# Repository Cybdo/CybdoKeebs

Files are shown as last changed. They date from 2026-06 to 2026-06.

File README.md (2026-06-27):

# CybdoKeebs!

A hotswappable ecosystem of i2c powered keyboard modules!

Zine

I made this project because I wanted to make something cooler than a macropad, and being able to just swap stuff around seemed really sick.

Inspired by [Ocreeb](https://www.youtube.com/watch?v=7DfexfHzT-w)!

# File structure

everything for each module is found under `modules/[module name]`, including CAD files, EDA files and firmware.

# Features
 - plug and play
 - hotswappable modules
 - exposed I2C buses
 - fully open source!
 - supports any MX-footprint keyswitches!
 - inbuilt USB hub in the controller

# Firmware
Firmware runs on circuitpython, and the firmware for each module is under `modules/[module name]/firmware`. Flash it using the SWD ports on each module, or via USB on the controller hub. You may need a SWD to USB converter, which can be made using a Raspberry Pi Pico.

# Custom modules
Each module is made as a composite of "sub units", each being 6cm tall and 5cm wide, with male pogo pins on the top and left sides, and female recievers on the bottom and right sides. These can be found here: https://www.aliexpress.com/item/1005005284441979.html

# Assembly
Everything is designed to be tray mounted, as to not obstruct the pogo pin assemblies! This means, the plate snaps into and are held up by keyswitches.

To put the keyboard together, put 4 keyswitches in each of the corners of the plate, then put the keyswitches through their sockets. After checking that everything is aligned, put in the rest of the switches!

assembled render

# BOM
found at `bom.csv`, assuming 1 controller hub, one keyboard and one macropad

# Schematics

## Hub


## Macropad



## Keyboard



# PCB

## Hub



## Macropad



## Keyboard




# Acknowledgements
 - [KiCad](https://www.kicad.org)
 - [Hack Club Fallout](https://fallout.hackclub.com)
 - [Ocreeb V2](https://github.com/sb-ocr/ocreeb-mk-2)
 - [CircuitPython](https://circuitpython.org/)
 - [ai03 Plate Generator](https://kbplate.ai03.com/)
 - [Hack Club Hackpad](https://hackpad.hackclub.com)

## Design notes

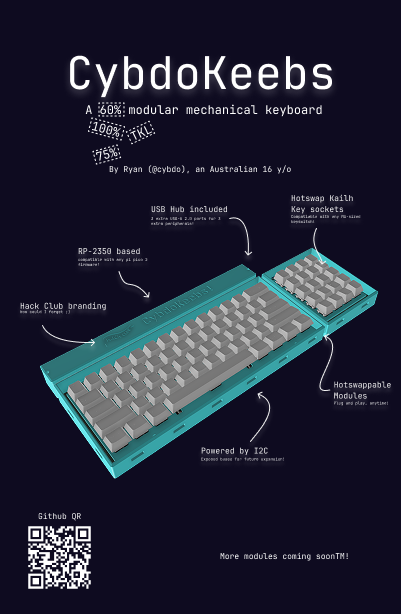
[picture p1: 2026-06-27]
assets/Zine.png

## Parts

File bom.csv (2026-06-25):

Item | Price ea (USD) | Qty | Price Total (USD) | Link | notes
bom-lcsc-minimum-system.xls (for 3 modules) | 17.82 | 1 | 13.87 | https://lcsc.com | for 3 modules accounting for MOQ, see bom-lcsc-minimum-system.xls and excl shipping
MX keyswitches 110 pcs | 19.62 | 1 | 19.62 | https://www.aliexpress.com/item/1005008998414457.html?curPageLogUid=2fVVZGWjHTVD
M3 screw 100pcs | 1.25 | 1 | 1.25 | https://www.aliexpress.com/item/32869840993.html
M3 heat set insert | 1 | 1 | 1 | https://www.aliexpress.com/item/1005004870993068.html
Kailh hot swap sockets 110 pcs | 5.61 | 1 | 5.61 | https://www.aliexpress.com/item/1005004290562374.html?scm_id=1007.10668.445195.0&scm-url=1007.10668.445195.0
PCB 5pcsof each | 49.59 | 1 | 49.59 | https://jlcpcb.com | including shipping
Stabiliser set | 1.53 | 1 | 1.53 | https://www.aliexpress.com/item/1005001543613992.html?curPageLogUid=S7IBJ0clB4Oz&utparam-url=scene%3Asearch|query_from%3A|x_object_id%3A1005001543613992|_p_origin_prod%3A
134 key keycap set | 3.17 | 1 | 3.17 | https://www.aliexpress.com/item/1005010601642425.html?curPageLogUid=OfD1pAizMWyY&utparam-url=scene%3Asearch|query_from%3A|x_object_id%3A1005010601642425|_p_origin_prod%3A&search_p4p_id=202606210629565832799410249750002134707_6
1N4148W | 0.0246 | 100 | 2.46 | https://www.lcsc.com/product-detail/C176288.html | for each keyswitch, not incl in lcsc bom
pogo pins 5pin 5pk | 6.46 | 4 | 25.84 | https://www.aliexpress.com/item/1005005284441979.html?curPageLogUid=fmbIcUrpBbfC
bom-lcsc-hub.xls (for the control hub) | 19.51 | 1 | 19.51 | https://lcsc.com | see bom-lcsc-hub.xls, excl shipping
TOTAL |  |  | 143.45

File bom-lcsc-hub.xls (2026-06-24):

bom_CybdoKeebs_hub.csv |  |  |  |  |  |  |  |  |  | LCSC BOM Quotation
 |  |  |  |  |  |  |  |  |  | BOM Date Created：24/06/26 18:42:51 |  |  |  | BOM Export Date: 24/06/26 18:52:30 |  |  |  | The matching result is a real-time query result, availability and prices may fluctuate. Backorder items are estimated prices for your reference, please submit "Create Quote" to get the real price. All information is provided "as is" and is subject to change without notice. Any use made of the information provided is without recourse to LCSC and at the user's risk.
 |  |  |  |  |  |  |  |  |  | EST TOTAL :$19.51 |  |  |  | Website：https://www.lcsc.com/bom | https://www.lcsc.com/bom | https://www.lcsc.com/bom | https://www.lcsc.com/bom
Uploaded data |  |  |  |  |  |  |  |  |  | LCSC Matching Results
LCSC# | Mfr. | Mrf# | Description | Package | Value | Customer Part Number | Quantity | Target Price(USD) | Target Lead Time(Business Days) | Mrf# | Mfr. | Order Qty. | Unit Price(USD) | Ext.Price(USD) | LCSC# | Package | Min | Mult | SPQ | Availability | Stock Status | Customer Notes | Description | Matched status | Product Link
 |  |  | 15pF | C_0402_1005Metric_Pad0.74x0.62mm_HandSolder |  | - | 4 |  |  | CL05C150JB5NNNC | Samsung Electro-Mechanics | 100 | 0.0059 | 0.59 | C86285 | 0402 | 100 | 100 | 10000 | 15700 | In Stock |  | 15pF ±5% 50V Ceramic Capacitor C0G 0402 | Partial Matches | https://www.lcsc.com/product-detail/C86285.html
 |  |  | 4.7uF | C_0402_1005Metric_Pad0.74x0.62mm_HandSolder |  | - | 3 |  |  | CL05A475KP5NRNC | Samsung Electro-Mechanics | 50 | 0.0116 | 0.58 | C368809 | 0402 | 50 | 50 | 10000 | 53050 | In Stock |  | 4.7uF ±10% 10V Ceramic Capacitor X5R 0402 | Partial Matches | https://www.lcsc.com/product-detail/C368809.html
 |  |  | 100nF | C_0402_1005Metric_Pad0.74x0.62mm_HandSolder |  | - | 11 |  |  | CC0402KRX7R7BB104 | YAGEO | 100 | 0.0115 | 1.15 | C60474 | 0402 | 100 | 100 | 10000 | 10000 | In Stock |  | 100nF ±10% 16V Ceramic Capacitor X7R 0402 | Partial Matches | https://www.lcsc.com/product-detail/C60474.html
 |  |  | 10uF | C_0402_1005Metric_Pad0.74x0.62mm_HandSolder |  | - | 3 |  |  | CL05A106MQ5NUNC | Samsung Electro-Mechanics | 100 | 0.0223 | 2.23 | C15525 | 0402 | 100 | 100 | 10000 | 126100 | In Stock |  | 10uF ±20% 6.3V Ceramic Capacitor X5R 0402 | Partial Matches | https://www.lcsc.com/product-detail/C15525.html
 |  |  | 1uF | C_0402_1005Metric_Pad0.74x0.62mm_HandSolder |  | - | 3 |  |  | CL05A105KO5NNNC | Samsung Electro-Mechanics | 100 | 0.0072 | 0.72 | C29266 | 0402 | 100 | 100 | 10000 | 29400 | In Stock |  | 1uF ±10% 16V Ceramic Capacitor X5R 0402 | Partial Matches | https://www.lcsc.com/product-detail/C29266.html
 |  |  | 1N5819WS | D_SOD-323 |  | - | 4 |  |  | 1N5819WS | Guangdong Hottech | 50 | 0.0107 | 0.54 | C191023 | SOD-323 | 50 | 50 | 3000 | 4200950 | In Stock |  | Diode 40V 1A Surface Mount SOD-323 | Partial Matches | https://www.lcsc.com/product-detail/C191023.html
C165948 |  |  | USB_C_Receptacle_USB2.0_14P | USB_C_Receptacle_HRO_TYPE-C-31-M-12 |  | - | 1 |  |  | TYPE-C-31-M-12 | Korean Hroparts Elec | 5 | 0.1857 | 0.93 | C165948 | SMD | 5 | 5 | 1000 | 90785 | In Stock |  | USB-C (USB TYPE-C) Receptacle Connector 16 Position Surface Mount | Exact Matches | https://www.lcsc.com/product-detail/C165948.html
 |  |  | Conn_01x05_Socket | pogo 5pin 2.54 |  |  | 6 |  |  | -(The data has been deleted.) | - | - | - | - | - | - | - | - | - | - | - | - | - | -
 |  |  | 3.3uF | INDC1608X95N |  | - | 1 |  |  | EGD2GM3R3E12OT | AISHI | 10 | 0.0407 | 0.41 | C106321 | Through Hole,D6.3xL12mm | 10 | 10 | 1000 | 28540 | In Stock |  | 3.3uF 400V Aluminum Electrolytic Capacitors Through Hole,D6.3xL12mm 6000hrs@105℃ | Partial Matches | https://www.lcsc.com/product-detail/C106321.html
 |  |  | 1kR | R_0402_1005Metric_Pad0.72x0.64mm_HandSolder |  | - | 3 |  |  | RT0402BRD071KL | YAGEO | 50 | 0.0199 | 1.00 | C852624 | 0402 | 50 | 50 | 10000 | 862800 | In Stock |  | 1kΩ 62.5mW 50V Thin Film Resistor ±25ppm/℃ ±0.1% 0402 Chip Resistor - Surface Mount RoHS | Partial Matches | https://www.lcsc.com/product-detail/C852624.html
 |  |  | 33R | R_0402_1005Metric_Pad0.72x0.64mm_HandSolder |  | - | 1 |  |  | RC0402JR-0733RL | YAGEO | 100 | 0.0011 | 0.11 | C137880 | 0402 | 100 | 100 | 10000 | 27700 | In Stock |  | 62.5mW 33Ω 50V Thick Film Resistor ±100ppm/℃ ±5% 0402 Chip Resistor - Surface Mount RoHS | Partial Matches | https://www.lcsc.com/product-detail/C137880.html
 |  |  | 27R | R_0402_1005Metric_Pad0.72x0.64mm_HandSolder |  | - | 2 |  |  | RT0402BRD0727RL | YAGEO | 50 | 0.0197 | 0.99 | C852682 | 0402 | 50 | 50 | 10000 | 8100 | In Stock |  | 63mW 27Ω Thin Film Resistor ±25ppm/℃ ±0.1% 0402 Chip Resistor - Surface Mount RoHS | Partial Matches | https://www.lcsc.com/product-detail/C852682.html
 |  |  | 10kR | R_0402_1005Metric_Pad0.72x0.64mm_HandSolder |  | - | 14 |  |  | RT0402BRD0710KL | YAGEO | 50 | 0.0207 | 1.04 | C190095 | 0402 | 50 | 50 | 10000 | 1079800 | In Stock |  | 62.5mW 10kΩ 50V Thin Film Resistor ±25ppm/℃ ±0.1% 0402 Chip Resistor - Surface Mount RoHS | Partial Matches | https://www.lcsc.com/product-detail/C190095.html
 |  | 0603WAF5101T5E | 5k1R | R_0402_1005Metric_Pad0.72x0.64mm_HandSolder |  | - | 2 |  |  | 0603WAF5101T5E | UNI-ROYAL | 100 | 0.0019 | 0.19 | C23186 | 0603 | 100 | 100 | 5000 | 0 | Backordered |  | 5.1kΩ ±1% 100mW 0603 Thick Film Resistor | Exact Matches | https://www.lcsc.com/product-detail/C23186.html
 |  | TS-1088-AR02016 | BOOTSEL | SW_Push_SPST_NO_Alps_SKRK |  | - | 1 |  |  | TS-1088-AR02016 | XUNPU | 10 | 0.0530 | 0.53 | C720477 | SMD,4x3mm | 10 | 10 | 4000 | 714210 | In Stock |  | Tactile Switch SPST 160gf 2mm SMD (SMT) Tab 4mm x 3mm Surface Mount | Exact Matches | https://www.lcsc.com/product-detail/C720477.html
 |  | TS-1088-AR02016 | RESET | SW_Push_SPST_NO_Alps_SKRK |  | - | 1 |  |  | TS-1088-AR02016 | XUNPU | 10 | 0.0530 | 0.53 | C720477 | SMD,4x3mm | 10 | 10 | 4000 | 714210 | In Stock |  | Tactile Switch SPST 160gf 2mm SMD (SMT) Tab 4mm x 3mm Surface Mount | Exact Matches | https://www.lcsc.com/product-detail/C720477.html
C41378174 |  |  | RP2350_60QFN | RP2350-QFN-60-1EP_7x7_P0.4mm_EP3.4x3.4mm_ThermalVias |  | - | 1 |  |  | RP2354A | Raspberry Pi | 1 | 1.3437 | 1.34 | C41378174 | QFN-60(7x7) | 1 | 1 | 3000 | 1139 | In Stock |  | QFN-60(7x7) Microcontrollers RoHS | Exact Matches | https://www.lcsc.com/product-detail/C41378174.html
 |  | MCP1700T-3302E/TT | MCP1700x-300xxTT | SOT-23 |  | - | 1 |  |  | MCP1700T-3302E/TT | MICROCHIP | 5 | 0.4372 | 2.19 | C39051 | SOT-23 | 5 | 5 | 3000 | 37130 | In Stock |  | 3.3V Positive Fixed SOT-23 Voltage Regulators - Linear, Low Drop Out (LDO) Regulators RoHS | Exact Matches | https://www.lcsc.com/product-detail/C39051.html
C2684433 |  |  | SL2.1S | SSOP-16_L4.6-W2.6-P0.53-LS4.0-BL |  | - | 1 |  |  | SL2.1s | CoreChips | 5 | 0.2534 | 1.27 | C2684433 | SSOP-16 | 5 | 5 | 7500 | 17710 | In Stock |  | Hub USB 2.0 SSOP-16 Interface Controllers RoHS | Exact Matches | https://www.lcsc.com/product-detail/C2684433.html
 |  |  | USBLC6-2P6 | SOT-666 |  | - | 4 |  |  | USBLC6-2P6 | ST | 5 | 0.2216 | 1.11 | C15999 | SOT-666-6 | 5 | 5 | 3000 | 43485 | In Stock |  | 17VC Clamp 5A@8/20us Ipp ESD DIODE SOT-666-6 | Partial Matches | https://www.lcsc.com/product-detail/C15999.html
 |  |  | TYPE-A-AF90 | USB-A-TH_U-A-24DD-Y-13 |  | - | 3 |  |  | U-A-24DD-Y-13 | Korean Hroparts Elec | 5 | 0.1160 | 0.58 | C2689984 | Through Hole | 5 | 5 | 100 | 3150 | In Stock |  | USB-A (USB TYPE-A) Receptacle Connector 4 Position Vertical, Flag | Partial Matches | https://www.lcsc.com/product-detail/C2689984.html
C20625731 |  |  | ABM8-272-T3 | Crystal_SMD_Abracon_ABM8G-4Pin_3.2x2.5mm |  | - | 2 |  |  | ABM8-272-T3 | ABRACON | 5 | 0.2956 | 1.48 | C20625731 | SMD3225-4P | 5 | 5 | 3000 | 10905 | In Stock |  | ±30ppm 10pF ±30ppm SMD3225-4P Crystals RoHS | Exact Matches | https://www.lcsc.com/product-detail/C20625731.html

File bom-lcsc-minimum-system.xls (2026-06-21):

bom_cybdokeebs_template.csv |  |  |  |  |  |  |  |  |  | LCSC BOM Quotation
 |  |  |  |  |  |  |  |  |  | BOM Date Created：21/06/26 21:21:24 |  |  |  | BOM Export Date: 21/06/26 21:24:42 |  |  |  | The matching result is a real-time query result, availability and prices may fluctuate. Backorder items are estimated prices for your reference, please submit "Create Quote" to get the real price. All information is provided "as is" and is subject to change without notice. Any use made of the information provided is without recourse to LCSC and at the user's risk.
 |  |  |  |  |  |  |  |  |  | EST TOTAL :$10.05 |  |  |  | Website：https://www.lcsc.com/bom | https://www.lcsc.com/bom | https://www.lcsc.com/bom | https://www.lcsc.com/bom
Uploaded data |  |  |  |  |  |  |  |  |  | LCSC Matching Results
LCSC# | Mfr. | Mrf# | Description | Package | Value | Customer Part Number | Quantity | Target Price(USD) | Target Lead Time(Business Days) | Mrf# | Mfr. | Order Qty. | Unit Price(USD) | Ext.Price(USD) | LCSC# | Package | Min | Mult | SPQ | Availability | Stock Status | Customer Notes | Description | Matched status | Product Link
 |  |  | 0.1uF | C_0402_1005Metric_Pad0.74x0.62mm_HandSolder |  | - | 2 |  |  | CC0402KRX7R7BB104 | YAGEO | 100 | 0.0102 | 1.02 | C60474 | 0402 | 100 | 100 | 10000 | 13400 | In Stock |  | 100nF ±10% 16V Ceramic Capacitor X7R 0402 | Partial Matches | https://www.lcsc.com/product-detail/C60474.html
 |  |  | 4.7uF | C_0402_1005Metric_Pad0.74x0.62mm_HandSolder |  | - | 4 |  |  | CL05A475KP5NRNC | Samsung Electro-Mechanics | 50 | 0.0117 | 0.59 | C368809 | 0402 | 50 | 50 | 10000 | 210900 | In Stock |  | 4.7uF ±10% 10V Ceramic Capacitor X5R 0402 | Partial Matches | https://www.lcsc.com/product-detail/C368809.html
 |  |  | 100nF | C_0402_1005Metric_Pad0.74x0.62mm_HandSolder |  | - | 11 |  |  | CC0402KRX7R7BB104 | YAGEO | 100 | 0.0102 | 1.02 | C60474 | 0402 | 100 | 100 | 10000 | 13400 | In Stock |  | 100nF ±10% 16V Ceramic Capacitor X7R 0402 | Partial Matches | https://www.lcsc.com/product-detail/C60474.html
 |  |  | Conn_01x05_Pin | pogo 5pin 2.54 |  |  | 4 |  |  | -(The data has been deleted.) | - | - | - | - | - | - | - | - | - | - | - | - | - | -
 |  |  | Conn_01x05_Socket | pogo 5pin 2.54 |  |  | 4 |  |  | -(The data has been deleted.) | - | - | - | - | - | - | - | - | - | - | - | - | - | -
 |  |  | 3.3uF | INDC1608X95N |  | - | 1 |  |  | EGD2GM3R3E12OT | AISHI | 10 | 0.0407 | 0.41 | C106321 | Through Hole,D6.3xL12mm | 10 | 10 | 1000 | 28540 | In Stock |  | 3.3uF 400V Aluminum Electrolytic Capacitors Through Hole,D6.3xL12mm 6000hrs@105℃ | Partial Matches | https://www.lcsc.com/product-detail/C106321.html
 |  |  | 10kR | R_0402_1005Metric_Pad0.72x0.64mm_HandSolder |  | - | 8 |  |  | FRC0402F1002TS | FOJAN | 100 | 0.0026 | 0.26 | C2906861 | 0402 | 100 | 100 | 10000 | 321700 | In Stock |  | 10kΩ ±1% 62.5mW 0402 Thick Film Resistor | Partial Matches | https://www.lcsc.com/product-detail/C2906861.html
 |  |  | 1kR | R_0402_1005Metric_Pad0.72x0.64mm_HandSolder |  | - | 2 |  |  | RT0402BRD071KL | YAGEO | 50 | 0.0199 | 1.00 | C852624 | 0402 | 50 | 50 | 10000 | 1124350 | In Stock |  | 1kΩ 62.5mW 50V Thin Film Resistor ±25ppm/℃ ±0.1% 0402 Chip Resistor - Surface Mount RoHS | Partial Matches | https://www.lcsc.com/product-detail/C852624.html
 |  | C720477 | BOOTSEL | SW_Push_SPST_NO_Alps_SKRK |  | - | 2 |  |  | TS-1088-AR02016 | XUNPU | 10 | 0.0530 | 0.53 | C720477 | SMD,4x3mm | 10 | 10 | 4000 | 765910 | In Stock |  | Tactile Switch SPST 160gf 2mm SMD (SMT) Tab 4mm x 3mm Surface Mount | Partial Matches | https://www.lcsc.com/product-detail/C720477.html
C880333 |  |  | TCA4307DGKR | VSSOP-8_L3.0-W3.0-P0.65-LS4.9-BL |  | - | 1 |  |  | TCA4307DGKR | TI | 1 | 2.5395 | 2.54 | C880333 | MSOP-8 | 1 | 1 | 2500 | 938 | In Stock |  | 2.3V~5.5V Buffer MSOP-8 Hot Swap Controllers RoHS | Exact Matches | https://www.lcsc.com/product-detail/C880333.html
 |  | C41378174 | RP2350_60QFN | RP2350-QFN-60-1EP_7x7_P0.4mm_EP3.4x3.4mm_ThermalVias |  | - | 1 |  |  | RP2354A | Raspberry Pi | 1 | 1.3437 | 1.34 | C41378174 | QFN-60(7x7) | 1 | 1 | 3000 | 3156 | In Stock |  | QFN-60(7x7) Microcontrollers RoHS | Partial Matches | https://www.lcsc.com/product-detail/C41378174.html
C160389 |  |  | BM03B-SRSS-TB | CONN-SMD-3P-P1.00_BM03B-SRSS-TB-LF-SN |  | - | 1 |  |  | BM03B-SRSS-TB(LF)(SN) | JST | 5 | 0.2683 | 1.34 | C160389 | SMD,P=1mm | 5 | 5 | 1500 | 7320 | In Stock |  | Connector Header 3 position 1mm Pitch 1A Surface Mount,Vertical -25℃~+85℃ | Exact Matches | https://www.lcsc.com/product-detail/C160389.html

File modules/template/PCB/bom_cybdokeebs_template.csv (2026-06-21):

Id | Designator | Footprint | Quantity | Designation | Supplier and ref
1 | C1, C2 | C_0402_1005Metric_Pad0.74x0.62mm_HandSolder | 2 | 0.1uF
2 | C3, C4, C5, C6 | C_0402_1005Metric_Pad0.74x0.62mm_HandSolder | 4 | 4.7uF
3 | C7, C8, C9, C10, C11, C12, C13, C14, C15, C16, C17 | C_0402_1005Metric_Pad0.74x0.62mm_HandSolder | 11 | 100nF
4 | J9, J10, J15, J16 | pogo 5pin 2.54 | 4 | Conn_01x05_Pin
5 | J11, J12, J13, J14 | pogo 5pin 2.54 | 4 | Conn_01x05_Socket
6 | L1 | INDC1608X95N | 1 | 3.3uF
7 | R1, R2, R3, R4, R5, R6, R7, R9 | R_0402_1005Metric_Pad0.72x0.64mm_HandSolder | 8 | 10kR
8 | R8, R10 | R_0402_1005Metric_Pad0.72x0.64mm_HandSolder | 2 | 1kR
9 | SW1, SW2 | SW_Push_SPST_NO_Alps_SKRK | 2 | BOOTSEL
10 | U1 | VSSOP-8_L3.0-W3.0-P0.65-LS4.9-BL | 1 | TCA4307DGKR
11 | U2 | RP2350-QFN-60-1EP_7x7_P0.4mm_EP3.4x3.4mm_ThermalVias | 1 | RP2350_60QFN
12 | U3 | CONN-SMD-3P-P1.00_BM03B-SRSS-TB-LF-SN | 1 | BM03B-SRSS-TB

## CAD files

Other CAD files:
modules/controller_hub/CAD/assembled.step
modules/keyboard/CAD/assembled.step
modules/macropad/CAD/assembled.step
assets/cybdokeebs.step
modules/controller_hub/pcb/imports/ABM8-272-T3.step
modules/controller_hub/pcb/pcb.step
modules/keyboard/PCB/pcb.step
modules/macropad/PCB/pcb.step
modules/controller_hub/CAD/top case.step
modules/keyboard/CAD/case.step
modules/macropad/CAD/plate.step
modules/controller_hub/CAD/case.step
modules/keyboard/CAD/plate.step
modules/macropad/CAD/case.step

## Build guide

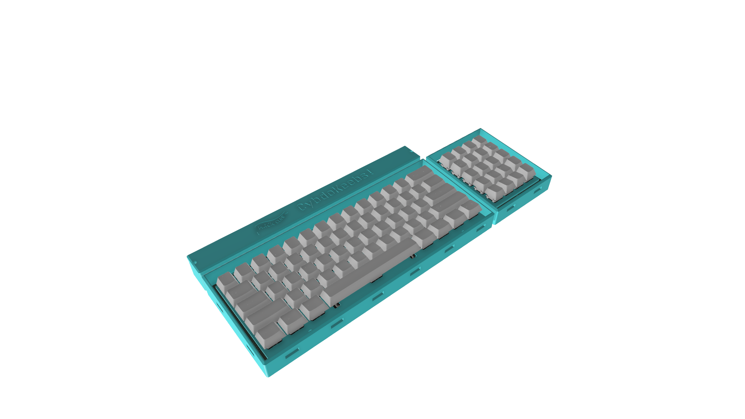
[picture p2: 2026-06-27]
assets/assembled render.png

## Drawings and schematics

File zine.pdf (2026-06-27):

# CybdoKeebs

# A 60% modular mechanical keyboard

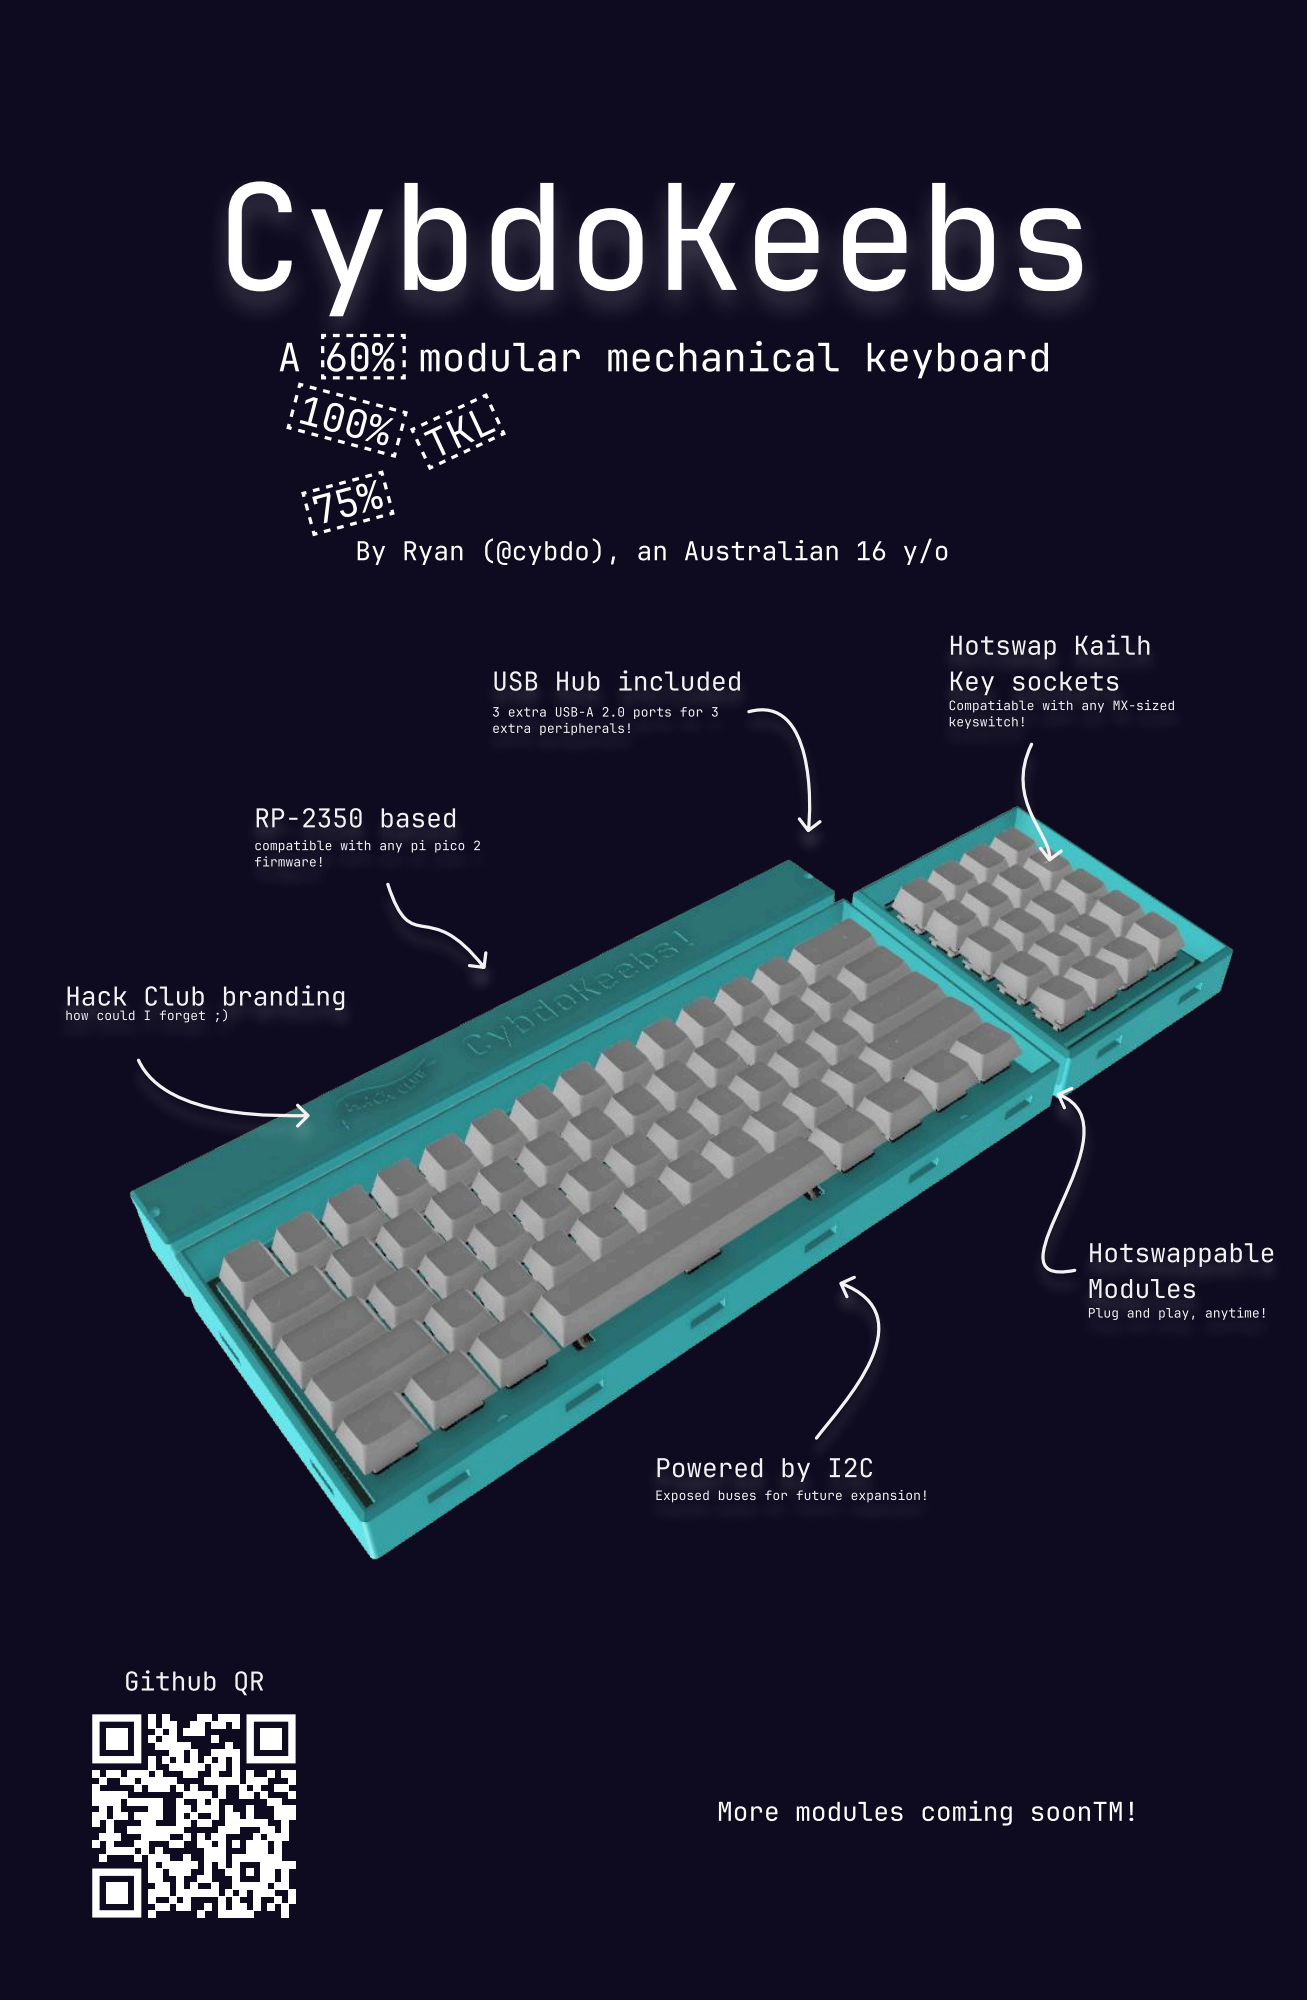
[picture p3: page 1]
TKL; Hotswap Kailh; Key sockets; RP-2350 based; Hotswappable; Modules; Powered by I2C; Github QR

By Ryan (@cybdo), an Australian 16 y/o

USB Hub included

3 extra USB-A 2.0 ports for 3
extra peripherals!

Compatiable with any MX-sized
keyswitch!

compatible with any pi pico 2
firmware!

Hack Club branding

how could I forget ;)

Plug and play, anytime!

Exposed buses for future expansion!

More modules coming soonTM!

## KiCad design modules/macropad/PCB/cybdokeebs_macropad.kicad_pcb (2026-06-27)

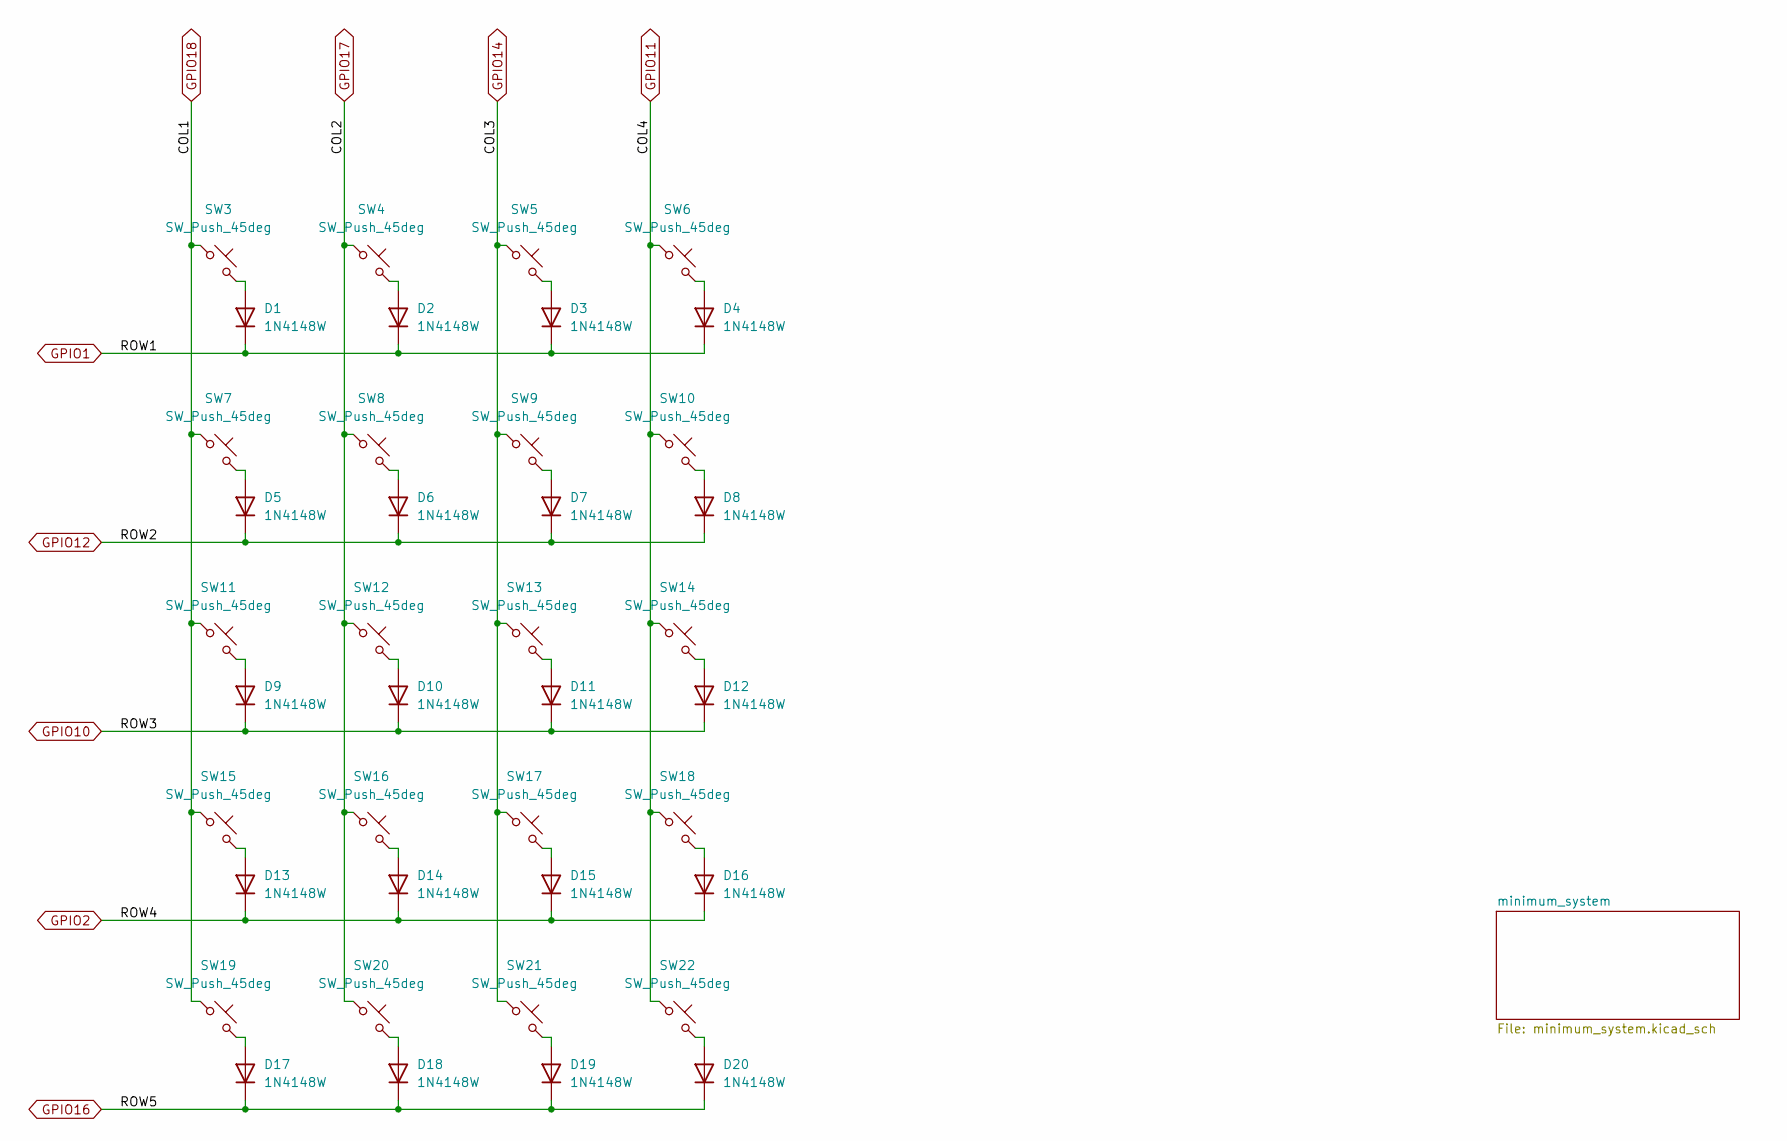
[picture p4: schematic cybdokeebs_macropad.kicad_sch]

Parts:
D1, D2, D3, D4, D5, D6, D7, D8, D9, D10, D11, D12, D13, D14, D15, D16, D17, D18, D19, D20: 1N4148W; D_SOD-123
SW3, SW4, SW5, SW6, SW7, SW8, SW9, SW10, SW11, SW12, SW13, SW14, SW15, SW16, SW17, SW18, SW19, SW20, SW21, SW22: SW_Push_45deg; SW_Hotswap_Kailh_MX_1.00u

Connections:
GPIO1: D1.1 (K), D2.1 (K), D3.1 (K), D4.1 (K); also elsewhere on the board
GPIO2: D13.1 (K), D14.1 (K), D15.1 (K), D16.1 (K); also elsewhere on the board
GPIO10: D9.1 (K), D10.1 (K), D11.1 (K), D12.1 (K); also elsewhere on the board
GPIO11: SW6.1, SW10.1, SW14.1, SW18.1, SW22.1; also elsewhere on the board
GPIO12: D5.1 (K), D6.1 (K), D7.1 (K), D8.1 (K); also elsewhere on the board
GPIO14: SW5.1, SW9.1, SW13.1, SW17.1, SW21.1; also elsewhere on the board
GPIO16: D17.1 (K), D18.1 (K), D19.1 (K), D20.1 (K); also elsewhere on the board
GPIO17: SW4.1, SW8.1, SW12.1, SW16.1, SW20.1; also elsewhere on the board
GPIO18: SW3.1, SW7.1, SW11.1, SW15.1, SW19.1; also elsewhere on the board
unnamed: D1.2 (A), SW3.2
unnamed: D2.2 (A), SW4.2
unnamed: D3.2 (A), SW5.2
unnamed: D4.2 (A), SW6.2
unnamed: D5.2 (A), SW7.2
unnamed: D6.2 (A), SW8.2
unnamed: D7.2 (A), SW9.2
unnamed: D8.2 (A), SW10.2
unnamed: D9.2 (A), SW11.2
unnamed: D10.2 (A), SW12.2
unnamed: D11.2 (A), SW13.2
unnamed: D12.2 (A), SW14.2
unnamed: D13.2 (A), SW15.2
unnamed: D14.2 (A), SW16.2
unnamed: D15.2 (A), SW17.2
unnamed: D16.2 (A), SW18.2
unnamed: D17.2 (A), SW19.2
unnamed: D18.2 (A), SW20.2
unnamed: D19.2 (A), SW21.2
unnamed: D20.2 (A), SW22.2

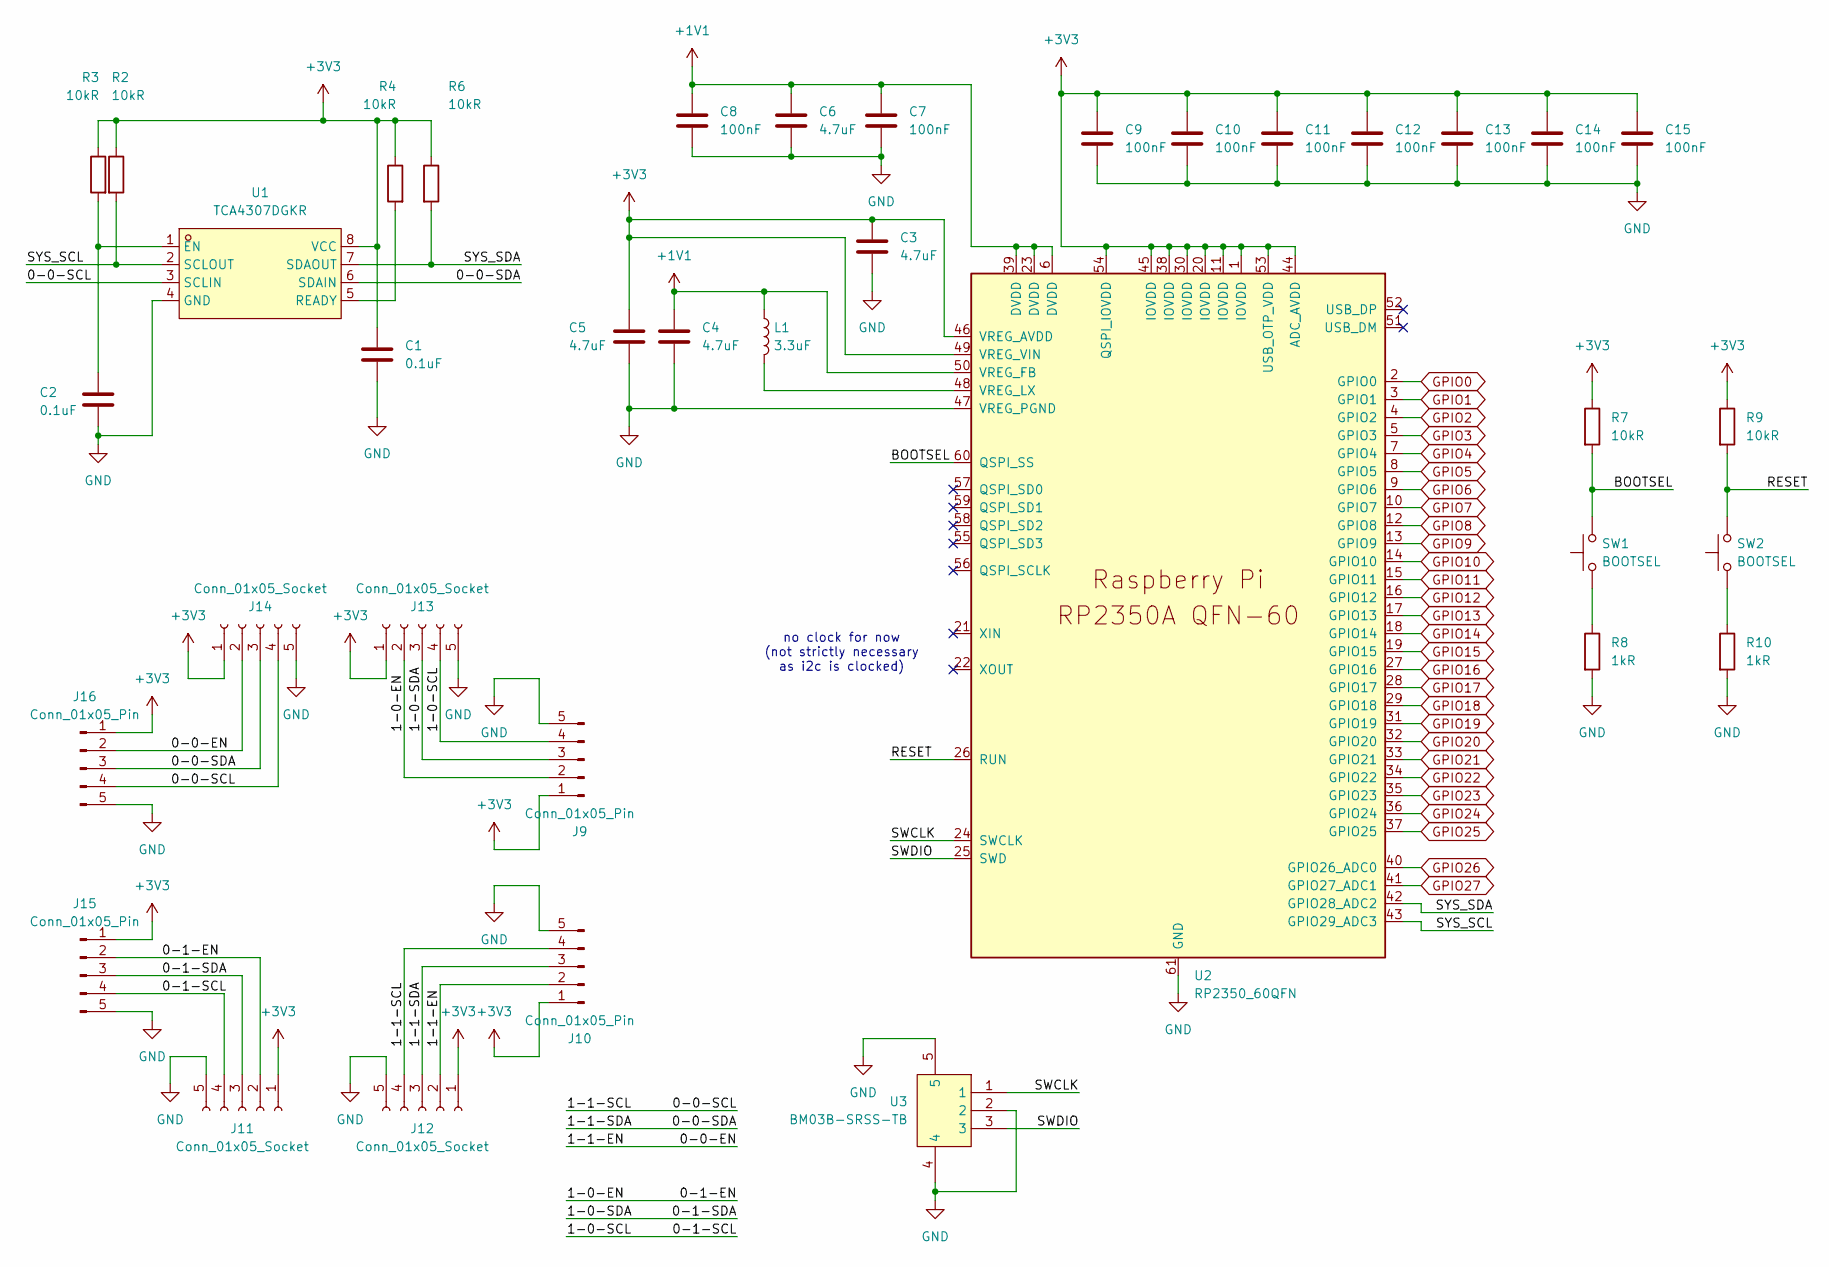
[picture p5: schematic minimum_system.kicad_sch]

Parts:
C1, C2: 0.1uF; C_0402_1005Metric_Pad0.74x0.62mm_HandSolder
C3, C4, C5, C6: 4.7uF; C_0402_1005Metric_Pad0.74x0.62mm_HandSolder
C7, C8, C9, C10, C11, C12, C13, C14, C15: 100nF; C_0402_1005Metric_Pad0.74x0.62mm_HandSolder
J9, J10, J15, J16: Conn_01x05_Pin; pogo 5pin 2.54
J11, J12, J13, J14: Conn_01x05_Socket; pogo 5pin 2.54
L1: 3.3uF; INDC1608X95N
R2, R3, R4, R6, R7, R9: 10kR; R_0402_1005Metric_Pad0.72x0.64mm_HandSolder
R8, R10: 1kR; R_0402_1005Metric_Pad0.72x0.64mm_HandSolder
SW1, SW2: BOOTSEL; SW_Push_SPST_NO_Alps_SKRK
U1: TCA4307DGKR; VSSOP-8_L3.0-W3.0-P0.65-LS4.9-BL; MPN TCA4307DGKR; LCSC Part C880333
U2: RP2350_60QFN; RP2350-QFN-60-1EP_7x7_P0.4mm_EP3.4x3.4mm_ThermalVias
U3: BM03B-SRSS-TB; CONN-SMD-3P-P1.00_BM03B-SRSS-TB-LF-SN; MPN BM03B-SRSS-TB(LF)(SN); LCSC Part C160389

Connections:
+1V1: C4.1, C6.1, C7.2, C8.1, L1.1, U2.6 (DVDD), U2.23 (DVDD), U2.39 (DVDD), U2.50 (VREG_FB)
+3V3: C1.1, C3.1, C5.2, C9.2, C10.2, C11.2, C12.2, C13.2, C14.2, C15.2, J9.1, J10.1, J11.1, J12.1, J13.1, J14.1, J15.1, J16.1, R2.1, R3.1, R4.1, R6.1, R7.1, R9.1, U1.8 (VCC), U2.1 (IOVDD), U2.11 (IOVDD), U2.20 (IOVDD), U2.30 (IOVDD), U2.38 (IOVDD), U2.44 (ADC_AVDD), U2.45 (IOVDD), U2.46 (VREG_AVDD), U2.49 (VREG_VIN), U2.53 (USB_OTP_VDD), U2.54 (QSPI_IOVDD)
/minimum_system/0-0-SCL: J10.4, J12.4, J14.4, J16.4, U1.3 (SCLIN)
/minimum_system/0-0-SDA: J10.3, J12.3, J14.3, J16.3, U1.6 (SDAIN)
/minimum_system/0-1-EN: J9.2, J11.2, J13.2, J15.2
/minimum_system/0-1-SCL: J9.4, J11.4, J13.4, J15.4
/minimum_system/0-1-SDA: J9.3, J11.3, J13.3, J15.3
/minimum_system/BOOTSEL: R7.2, SW1.2, U2.60 (QSPI_SS)
/minimum_system/RESET: R9.2, SW2.2, U2.26 (RUN)
/minimum_system/SWCLK: U2.24 (SWCLK), U3.1
/minimum_system/SWDIO: U2.25 (SWD), U3.3
/minimum_system/SYS_SCL: R2.2, U1.2 (SCLOUT), U2.43 (GPIO29_ADC3)
/minimum_system/SYS_SDA: R6.2, U1.7 (SDAOUT), U2.42 (GPIO28_ADC2)
GND: C1.2, C2.2, C3.2, C4.2, C5.1, C6.2, C7.1, C8.2, C9.1, C10.1, C11.1, C12.1, C13.1, C14.1, C15.1, J9.5, J10.5, J11.5, J12.5, J13.5, J14.5, J15.5, J16.5, R8.2, R10.2, U1.4 (GND), U2.47 (VREG_PGND), U2.61 (GND), U3.2, U3.4, U3.5
GPIO0: U2.2 (GPIO0)
GPIO1: U2.3 (GPIO1); also elsewhere on the board
GPIO2: U2.4 (GPIO2); also elsewhere on the board
GPIO3: U2.5 (GPIO3)
GPIO4: U2.7 (GPIO4)
GPIO5: U2.8 (GPIO5)
GPIO6: U2.9 (GPIO6)
GPIO7: U2.10 (GPIO7)
GPIO8: U2.12 (GPIO8)
GPIO9: U2.13 (GPIO9)
GPIO10: U2.14 (GPIO10); also elsewhere on the board
GPIO11: U2.15 (GPIO11); also elsewhere on the board
GPIO12: U2.16 (GPIO12); also elsewhere on the board
GPIO13: U2.17 (GPIO13)
GPIO14: U2.18 (GPIO14); also elsewhere on the board
GPIO15: U2.19 (GPIO15)
GPIO16: U2.27 (GPIO16); also elsewhere on the board
GPIO17: U2.28 (GPIO17); also elsewhere on the board
GPIO18: U2.29 (GPIO18); also elsewhere on the board
GPIO19: U2.31 (GPIO19)
GPIO20: U2.32 (GPIO20)
GPIO21: U2.33 (GPIO21)
GPIO23: U2.35 (GPIO23)
GPIO24: U2.36 (GPIO24)
GPIO25: U2.37 (GPIO25)
GPIO26: U2.40 (GPIO26_ADC0)
GPIO27: U2.41 (GPIO27_ADC1)
unnamed: R8.1, SW1.1
unnamed: R10.1, SW2.1
unnamed: C2.1, R3.2, U1.1 (EN)
unnamed: R4.2, U1.5 (READY)
unnamed: L1.2, U2.48 (VREG_LX)

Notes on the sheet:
no clock for now (not strictly necessary as i2c is clocked)

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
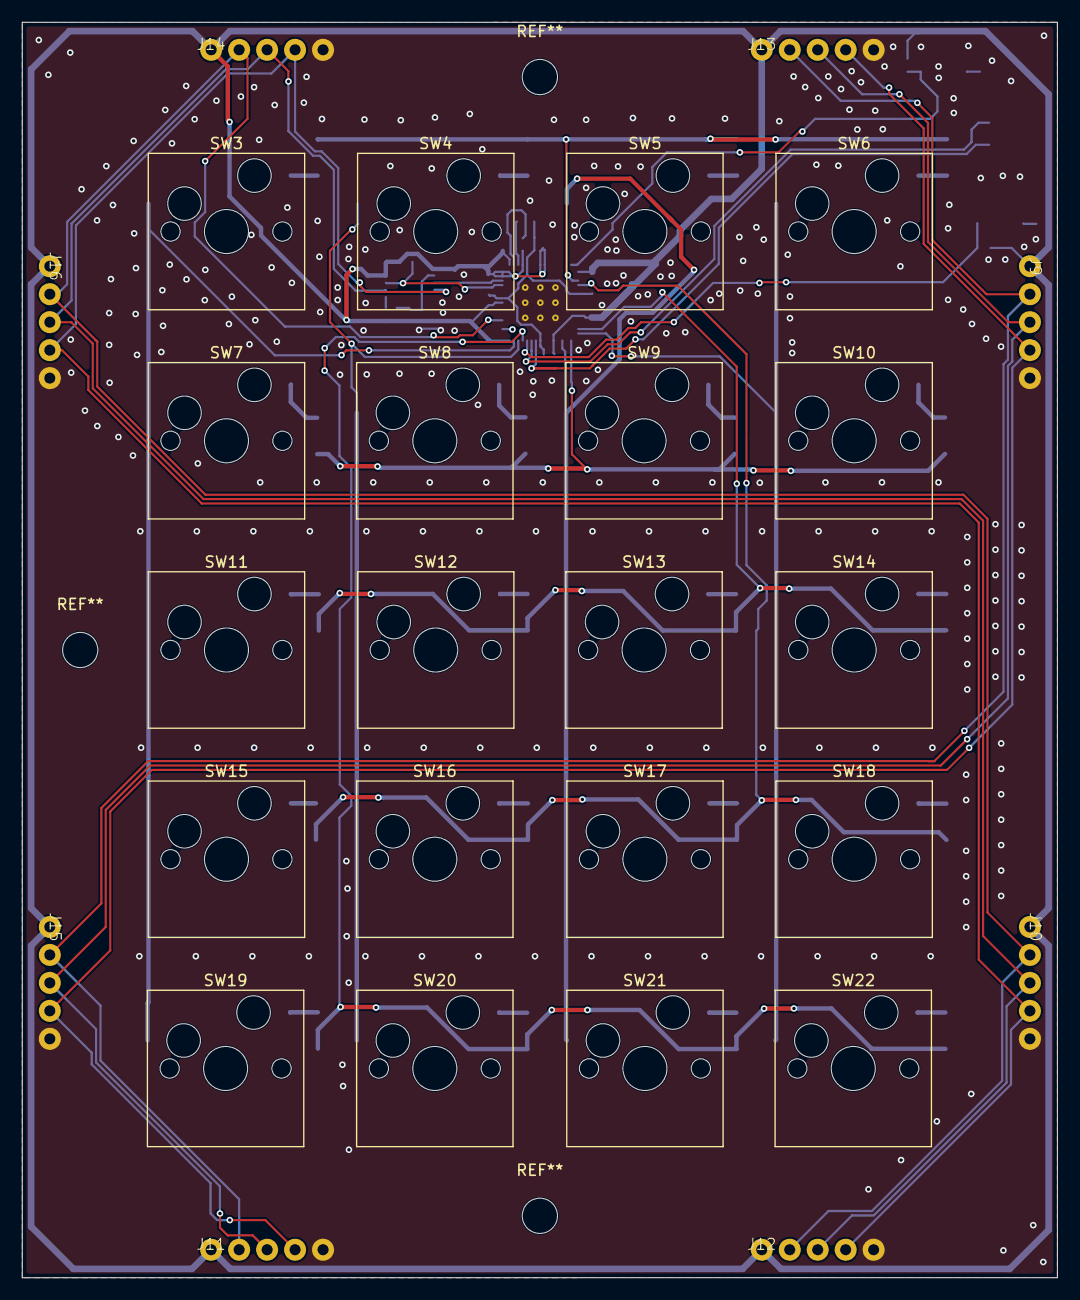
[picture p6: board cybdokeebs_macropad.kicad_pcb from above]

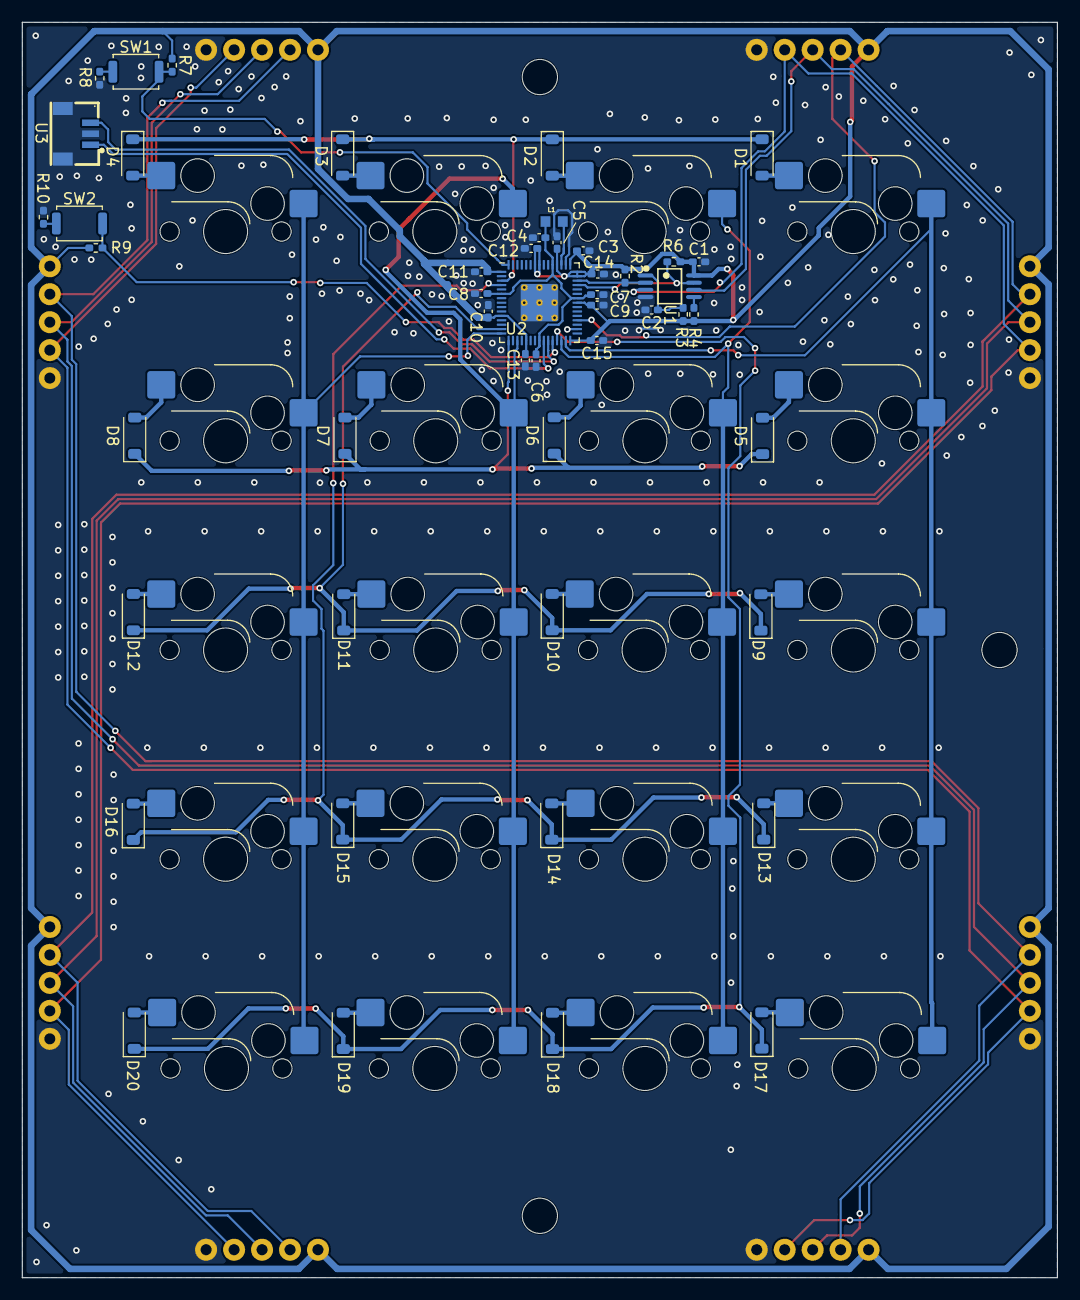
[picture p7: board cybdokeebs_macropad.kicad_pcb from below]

Board: 2 copper layers, 94.0 x 114.0 mm, 77 parts (49 on the bottom side), 49 nets.

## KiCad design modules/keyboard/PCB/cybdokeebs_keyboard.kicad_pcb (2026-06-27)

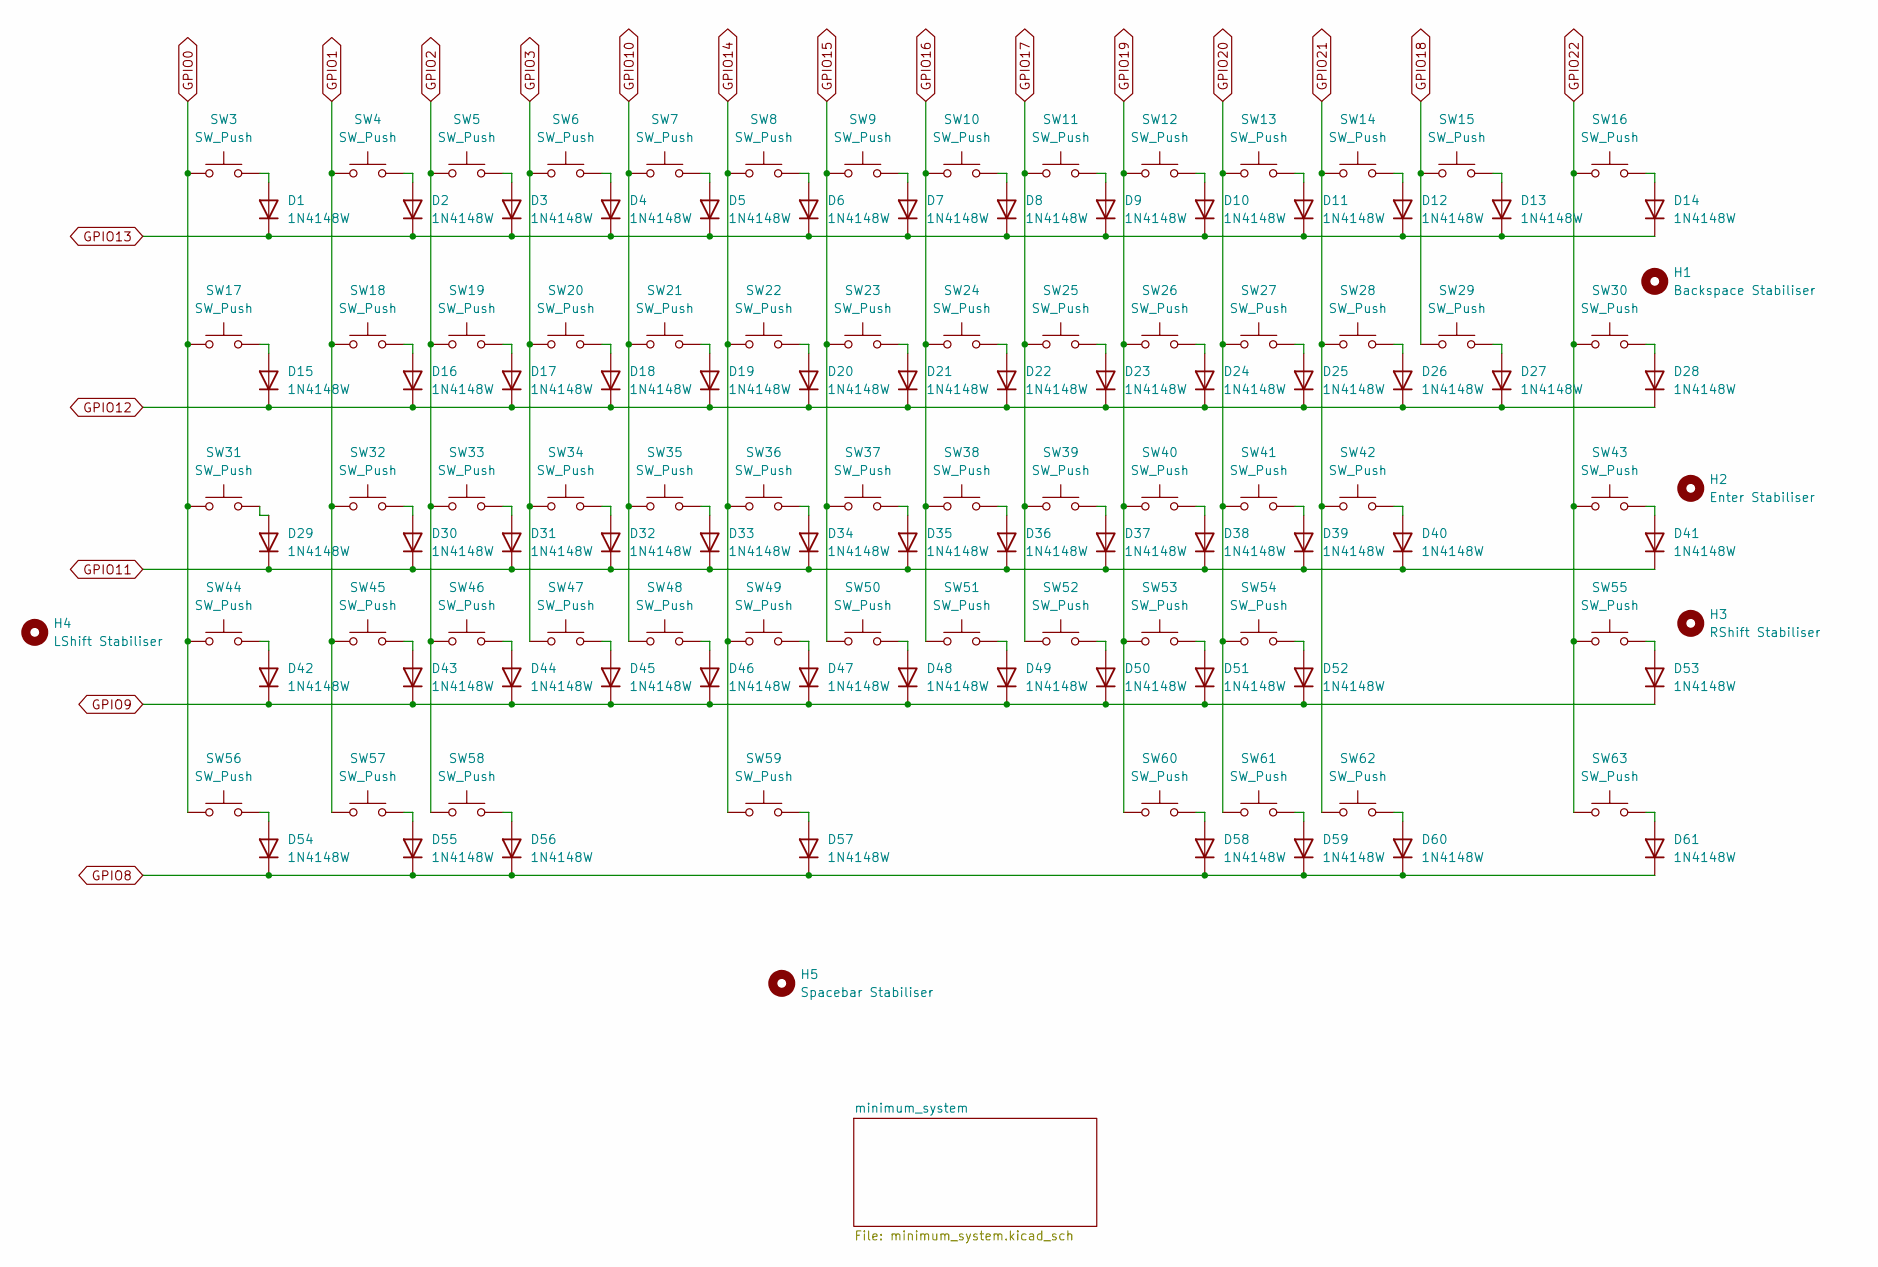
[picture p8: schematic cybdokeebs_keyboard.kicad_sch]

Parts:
D1, D2, D3, D4, D5, D6, D7, D8, D9, D10, D11, D12, D13, D14, D15, D16, D17, D18, D19, D20, D21, D22, D23, D24, D25, D26, D27, D28, D29, D30, D31, D32, D33, D34, D35, D36, D37, D38, D39, D40, D41, D42, D43, D44, D45, D46, D47, D48, D49, D50, D51, D52, D53, D54, D55, D56, D57, D58, D59, D60, D61: 1N4148W; D_SOD-123
H1: Backspace Stabiliser; Stabilizer_Cherry_MX_2.00u
H2: Enter Stabiliser; Stabilizer_Cherry_MX_2.00u
H3: RShift Stabiliser; Stabilizer_Cherry_MX_2.00u
H4: LShift Stabiliser; Stabilizer_Cherry_MX_2.00u
H5: Spacebar Stabiliser; Stabilizer_Cherry_MX_6.25u
SW3, SW4, SW5, SW6, SW7, SW8, SW9, SW10, SW11, SW12, SW13, SW14, SW15, SW18, SW19, SW20, SW21, SW22, SW23, SW24, SW25, SW26, SW27, SW28, SW29, SW32, SW33, SW34, SW35, SW36, SW37, SW38, SW39, SW40, SW41, SW42, SW45, SW46, SW47, SW48, SW49, SW50, SW51, SW52, SW53, SW54: SW_Push; SW_Hotswap_Kailh_MX_1.00u
SW16: SW_Push; SW_Hotswap_Kailh_MX_2.00u
SW17, SW30: SW_Push; SW_Hotswap_Kailh_MX_1.50u
SW31: SW_Push; SW_Hotswap_Kailh_MX_1.75u
SW43, SW44: SW_Push; SW_Hotswap_Kailh_MX_2.25u
SW55: SW_Push; SW_Hotswap_Kailh_MX_2.75u
SW56, SW57, SW58, SW60, SW61, SW62, SW63: SW_Push; SW_Hotswap_Kailh_MX_1.25u
SW59: SW_Push; SW_Hotswap_Kailh_MX_6.25u

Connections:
GPIO0: SW3.1, SW17.1, SW31.1, SW44.1, SW56.1; also elsewhere on the board
GPIO1: SW4.1, SW18.1, SW32.1, SW45.1, SW57.1; also elsewhere on the board
GPIO2: SW5.1, SW19.1, SW33.1, SW46.1, SW58.1; also elsewhere on the board
GPIO3: SW6.1, SW20.1, SW34.1, SW47.1; also elsewhere on the board
GPIO8: D54.1 (K), D55.1 (K), D56.1 (K), D57.1 (K), D58.1 (K), D59.1 (K), D60.1 (K), D61.1 (K); also elsewhere on the board
GPIO9: D42.1 (K), D43.1 (K), D44.1 (K), D45.1 (K), D46.1 (K), D47.1 (K), D48.1 (K), D49.1 (K), D50.1 (K), D51.1 (K), D52.1 (K), D53.1 (K); also elsewhere on the board
GPIO10: SW7.1, SW21.1, SW35.1, SW48.1; also elsewhere on the board
GPIO11: D29.1 (K), D30.1 (K), D31.1 (K), D32.1 (K), D33.1 (K), D34.1 (K), D35.1 (K), D36.1 (K), D37.1 (K), D38.1 (K), D39.1 (K), D40.1 (K), D41.1 (K); also elsewhere on the board
GPIO12: D15.1 (K), D16.1 (K), D17.1 (K), D18.1 (K), D19.1 (K), D20.1 (K), D21.1 (K), D22.1 (K), D23.1 (K), D24.1 (K), D25.1 (K), D26.1 (K), D27.1 (K), D28.1 (K); also elsewhere on the board
GPIO13: D1.1 (K), D2.1 (K), D3.1 (K), D4.1 (K), D5.1 (K), D6.1 (K), D7.1 (K), D8.1 (K), D9.1 (K), D10.1 (K), D11.1 (K), D12.1 (K), D13.1 (K), D14.1 (K); also elsewhere on the board
GPIO14: SW8.1, SW22.1, SW36.1, SW49.1, SW59.1; also elsewhere on the board
GPIO15: SW9.1, SW23.1, SW37.1, SW50.1; also elsewhere on the board
GPIO16: SW10.1, SW24.1, SW38.1, SW51.1; also elsewhere on the board
GPIO17: SW11.1, SW25.1, SW39.1, SW52.1; also elsewhere on the board
GPIO18: SW15.1, SW29.1; also elsewhere on the board
GPIO19: SW12.1, SW26.1, SW40.1, SW53.1, SW60.1; also elsewhere on the board
GPIO20: SW13.1, SW27.1, SW41.1, SW54.1, SW61.1; also elsewhere on the board
GPIO21: SW14.1, SW28.1, SW42.1, SW62.1; also elsewhere on the board
GPIO22: SW16.1, SW30.1, SW43.1, SW55.1, SW63.1; also elsewhere on the board
unnamed: D1.2 (A), SW3.2
unnamed: D2.2 (A), SW4.2
unnamed: D3.2 (A), SW5.2
unnamed: D4.2 (A), SW6.2
unnamed: D5.2 (A), SW7.2
unnamed: D6.2 (A), SW8.2
unnamed: D7.2 (A), SW9.2
unnamed: D8.2 (A), SW10.2
unnamed: D9.2 (A), SW11.2
unnamed: D10.2 (A), SW12.2
unnamed: D11.2 (A), SW13.2
unnamed: D12.2 (A), SW14.2
unnamed: D13.2 (A), SW15.2
unnamed: D14.2 (A), SW16.2
unnamed: D15.2 (A), SW17.2
unnamed: D16.2 (A), SW18.2
unnamed: D17.2 (A), SW19.2
unnamed: D18.2 (A), SW20.2
unnamed: D19.2 (A), SW21.2
unnamed: D20.2 (A), SW22.2
unnamed: D21.2 (A), SW23.2
unnamed: D22.2 (A), SW24.2
unnamed: D23.2 (A), SW25.2
unnamed: D24.2 (A), SW26.2
unnamed: D25.2 (A), SW27.2
unnamed: D26.2 (A), SW28.2
unnamed: D27.2 (A), SW29.2
unnamed: D28.2 (A), SW30.2
unnamed: D29.2 (A), SW31.2
unnamed: D30.2 (A), SW32.2
unnamed: D31.2 (A), SW33.2
unnamed: D32.2 (A), SW34.2
unnamed: D33.2 (A), SW35.2
unnamed: D34.2 (A), SW36.2
unnamed: D35.2 (A), SW37.2
unnamed: D36.2 (A), SW38.2
unnamed: D37.2 (A), SW39.2
unnamed: D38.2 (A), SW40.2
unnamed: D39.2 (A), SW41.2
unnamed: D40.2 (A), SW42.2
unnamed: D41.2 (A), SW43.2
unnamed: D42.2 (A), SW44.2
unnamed: D43.2 (A), SW45.2
unnamed: D44.2 (A), SW46.2
unnamed: D45.2 (A), SW47.2
unnamed: D46.2 (A), SW48.2
unnamed: D47.2 (A), SW49.2
unnamed: D48.2 (A), SW50.2
unnamed: D49.2 (A), SW51.2
unnamed: D50.2 (A), SW52.2
unnamed: D51.2 (A), SW53.2
unnamed: D52.2 (A), SW54.2
unnamed: D53.2 (A), SW55.2
unnamed: D54.2 (A), SW56.2
unnamed: D55.2 (A), SW57.2
unnamed: D56.2 (A), SW58.2
unnamed: D57.2 (A), SW59.2
unnamed: D58.2 (A), SW60.2
unnamed: D59.2 (A), SW61.2
unnamed: D60.2 (A), SW62.2
unnamed: D61.2 (A), SW63.2

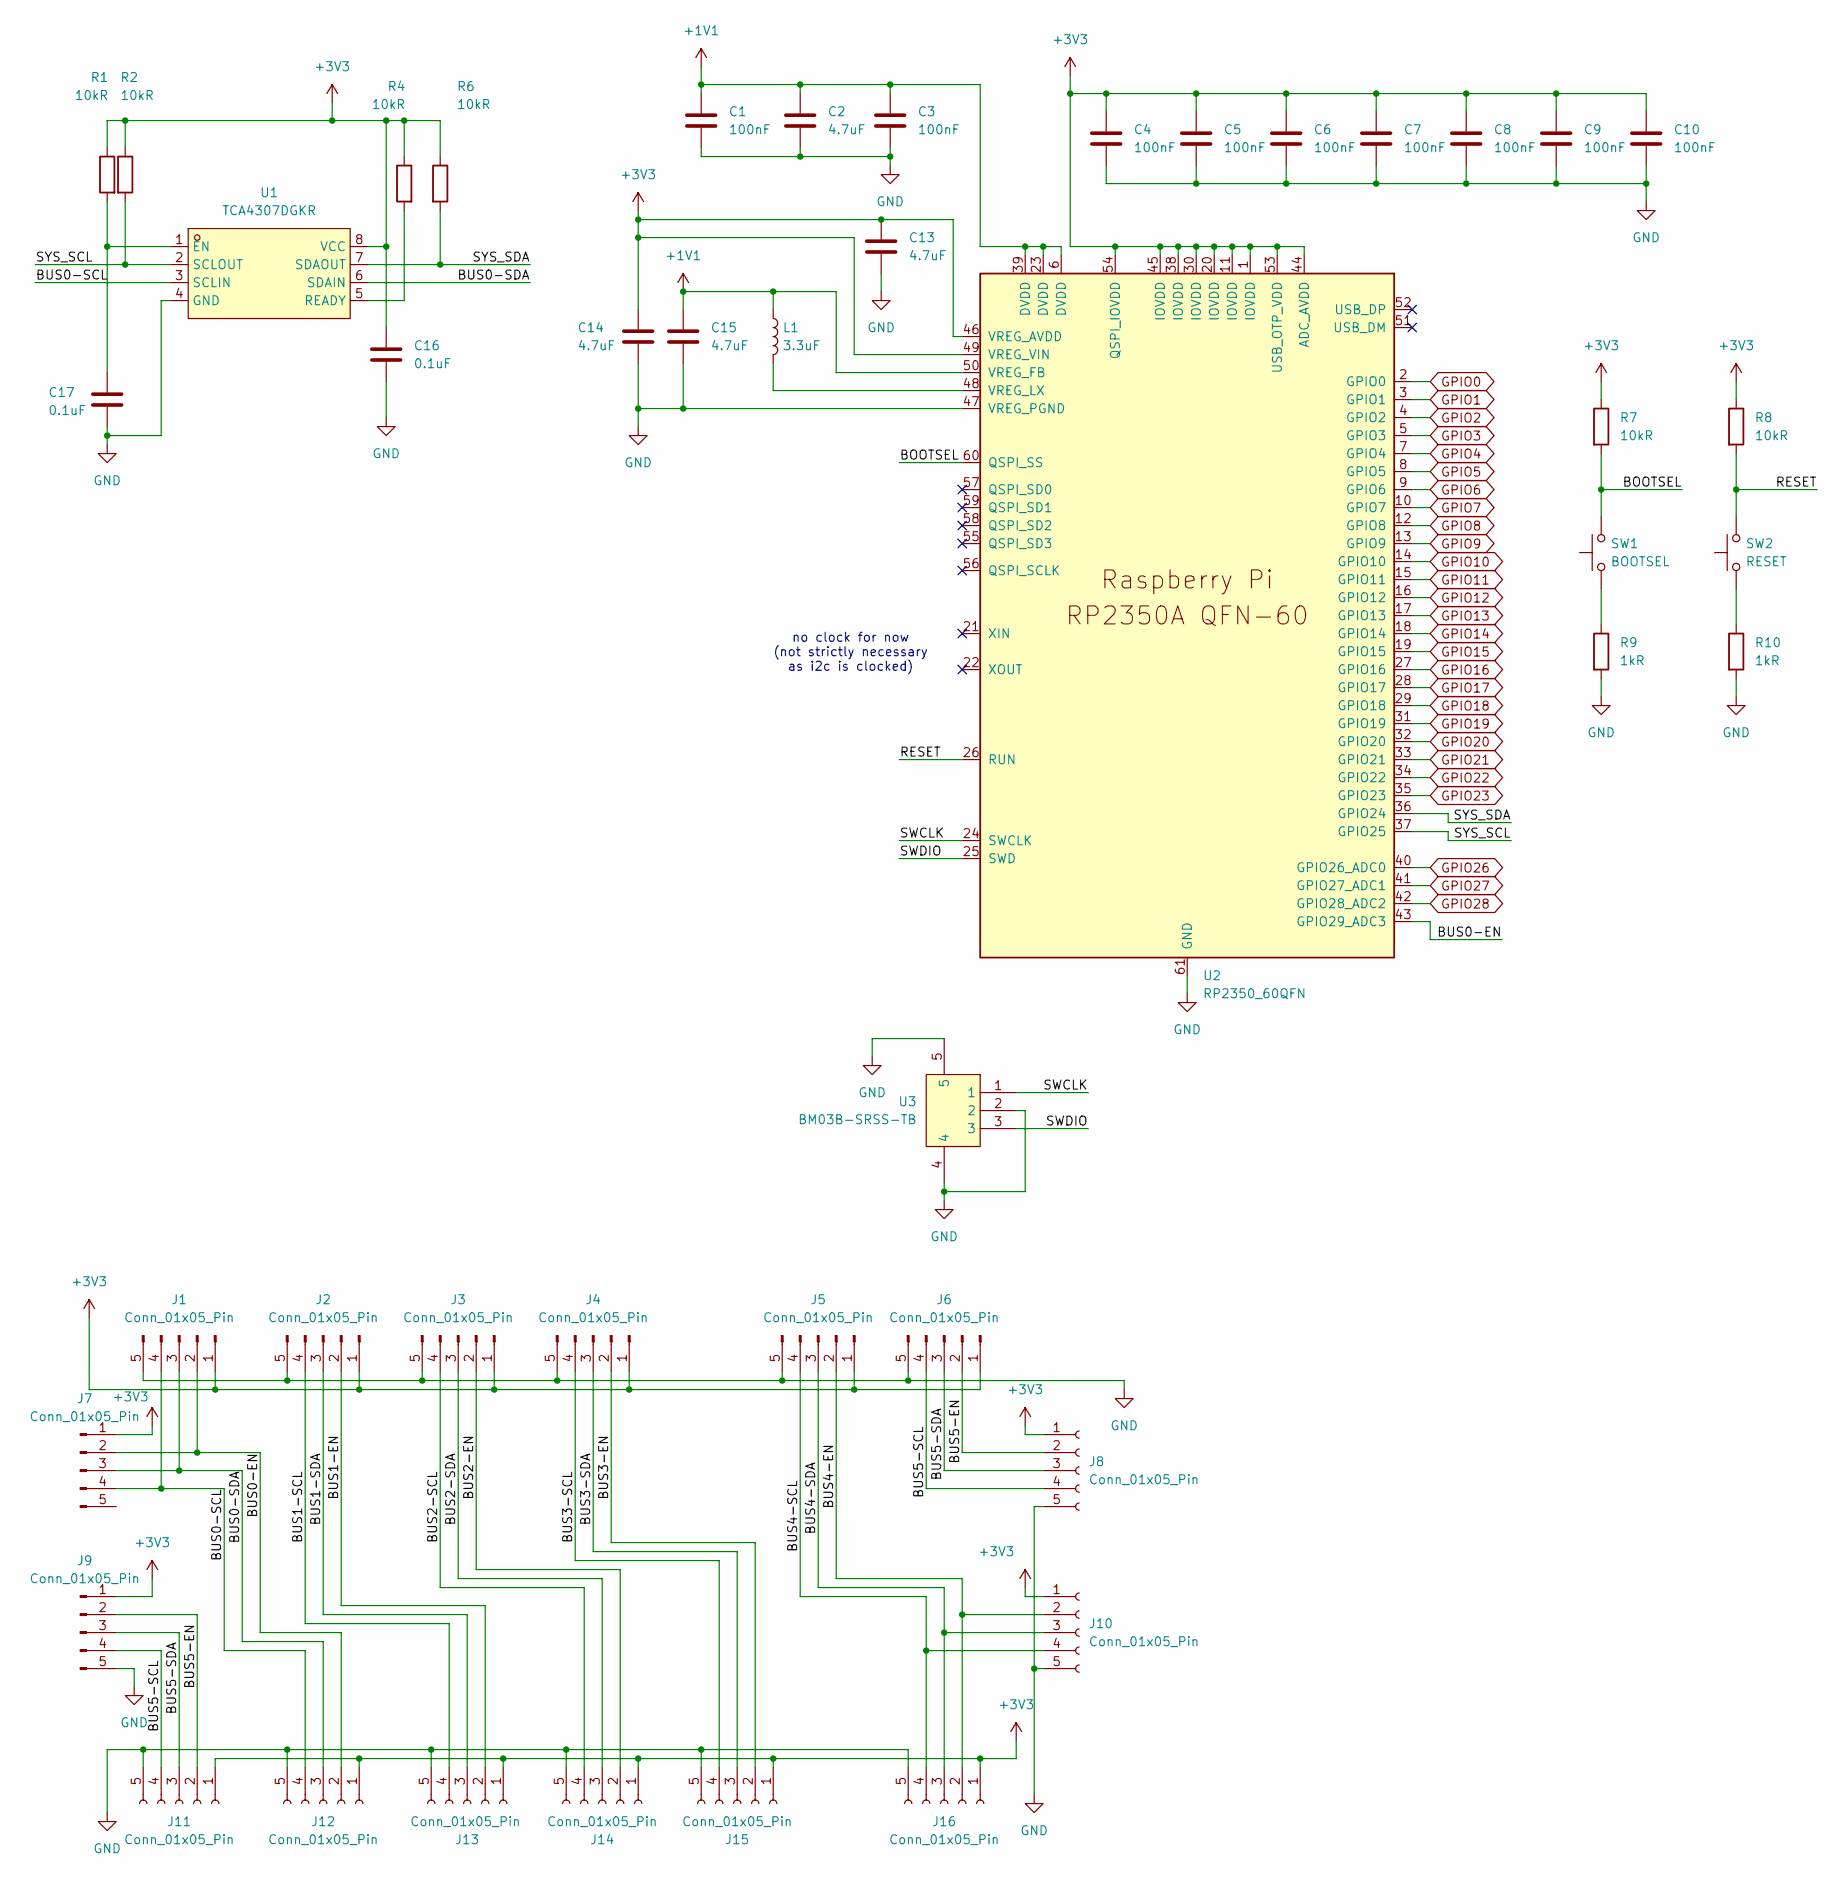
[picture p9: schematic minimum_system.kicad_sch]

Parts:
C1, C3, C4, C5, C6, C7, C8, C9, C10: 100nF; C_0402_1005Metric_Pad0.74x0.62mm_HandSolder
C2, C13, C14, C15: 4.7uF; C_0402_1005Metric_Pad0.74x0.62mm_HandSolder
C16, C17: 0.1uF; C_0402_1005Metric_Pad0.74x0.62mm_HandSolder
J1, J2, J3, J4, J5, J6, J7, J8, J9, J10, J11, J12, J13, J14, J15, J16: Conn_01x05_Pin; pogo 5pin 2.54
L1: 3.3uF; INDC1608X95N
R1, R2, R4, R6, R7, R8: 10kR; R_0402_1005Metric_Pad0.72x0.64mm_HandSolder
R9, R10: 1kR; R_0402_1005Metric_Pad0.72x0.64mm_HandSolder
SW1: BOOTSEL; SW_Push_SPST_NO_Alps_SKRK
SW2: RESET; SW_Push_SPST_NO_Alps_SKRK
U1: TCA4307DGKR; VSSOP-8_L3.0-W3.0-P0.65-LS4.9-BL; MPN TCA4307DGKR; LCSC Part C880333
U2: RP2350_60QFN; RP2350-QFN-60-1EP_7x7_P0.4mm_EP3.4x3.4mm_ThermalVias
U3: BM03B-SRSS-TB; CONN-SMD-3P-P1.00_BM03B-SRSS-TB-LF-SN; MPN BM03B-SRSS-TB(LF)(SN); LCSC Part C160389

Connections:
+1V1: C1.1, C2.1, C3.2, C15.1, L1.1, U2.6 (DVDD), U2.23 (DVDD), U2.39 (DVDD), U2.50 (VREG_FB)
+3V3: C4.2, C5.2, C6.2, C7.2, C8.2, C9.2, C10.2, C13.1, C14.2, C16.1, J1.1, J2.1, J3.1, J4.1, J5.1, J6.1, J7.1, J8.1, J9.1, J10.1, J11.1, J12.1, J13.1, J14.1, J15.1, J16.1, R1.1, R2.1, R4.1, R6.1, R7.1, R8.1, U1.8 (VCC), U2.1 (IOVDD), U2.11 (IOVDD), U2.20 (IOVDD), U2.30 (IOVDD), U2.38 (IOVDD), U2.44 (ADC_AVDD), U2.45 (IOVDD), U2.46 (VREG_AVDD), U2.49 (VREG_VIN), U2.53 (USB_OTP_VDD), U2.54 (QSPI_IOVDD)
/minimum_system/BOOTSEL: R7.2, SW1.2, U2.60 (QSPI_SS)
/minimum_system/BUS0-EN: J1.2, J7.2, J12.2, U2.43 (GPIO29_ADC3)
/minimum_system/BUS0-SCL: J1.4, J7.4, J12.4, U1.3 (SCLIN)
/minimum_system/BUS0-SDA: J1.3, J7.3, J12.3, U1.6 (SDAIN)
/minimum_system/BUS1-EN: J2.2, J13.2
/minimum_system/BUS1-SCL: J2.4, J13.4
/minimum_system/BUS1-SDA: J2.3, J13.3
/minimum_system/BUS2-EN: J3.2, J14.2
/minimum_system/BUS2-SCL: J3.4, J14.4
/minimum_system/BUS2-SDA: J3.3, J14.3
/minimum_system/BUS3-EN: J4.2, J15.2
/minimum_system/BUS3-SCL: J4.4, J15.4
/minimum_system/BUS3-SDA: J4.3, J15.3
/minimum_system/BUS4-EN: J5.2, J10.2, J16.2
/minimum_system/BUS4-SCL: J5.4, J10.4, J16.4
/minimum_system/BUS4-SDA: J5.3, J10.3, J16.3
/minimum_system/BUS5-EN: J6.2, J8.2, J9.2, J11.2
/minimum_system/BUS5-SCL: J6.4, J8.4, J9.4, J11.4
/minimum_system/BUS5-SDA: J6.3, J8.3, J9.3, J11.3
/minimum_system/RESET: R8.2, SW2.2, U2.26 (RUN)
/minimum_system/SWCLK: U2.24 (SWCLK), U3.1
/minimum_system/SWDIO: U2.25 (SWD), U3.3
/minimum_system/SYS_SCL: R2.2, U1.2 (SCLOUT), U2.37 (GPIO25)
/minimum_system/SYS_SDA: R6.2, U1.7 (SDAOUT), U2.36 (GPIO24)
GND: C1.2, C2.2, C3.1, C4.1, C5.1, C6.1, C7.1, C8.1, C9.1, C10.1, C13.2, C14.1, C15.2, C16.2, C17.2, J1.5, J2.5, J3.5, J4.5, J5.5, J6.5, J8.5, J9.5, J10.5, J11.5, J12.5, J13.5, J14.5, J15.5, J16.5, R9.2, R10.2, U1.4 (GND), U2.47 (VREG_PGND), U2.61 (GND), U3.2, U3.4, U3.5
GPIO0: U2.2 (GPIO0); also elsewhere on the board
GPIO1: U2.3 (GPIO1); also elsewhere on the board
GPIO2: U2.4 (GPIO2); also elsewhere on the board
GPIO3: U2.5 (GPIO3); also elsewhere on the board
GPIO4: U2.7 (GPIO4)
GPIO5: U2.8 (GPIO5)
GPIO6: U2.9 (GPIO6)
GPIO7: U2.10 (GPIO7)
GPIO8: U2.12 (GPIO8); also elsewhere on the board
GPIO9: U2.13 (GPIO9); also elsewhere on the board
GPIO10: U2.14 (GPIO10); also elsewhere on the board
GPIO11: U2.15 (GPIO11); also elsewhere on the board
GPIO12: U2.16 (GPIO12); also elsewhere on the board
GPIO13: U2.17 (GPIO13); also elsewhere on the board
GPIO14: U2.18 (GPIO14); also elsewhere on the board
GPIO15: U2.19 (GPIO15); also elsewhere on the board
GPIO16: U2.27 (GPIO16); also elsewhere on the board
GPIO17: U2.28 (GPIO17); also elsewhere on the board
GPIO18: U2.29 (GPIO18); also elsewhere on the board
GPIO19: U2.31 (GPIO19); also elsewhere on the board
GPIO20: U2.32 (GPIO20); also elsewhere on the board
GPIO21: U2.33 (GPIO21); also elsewhere on the board
GPIO22: U2.34 (GPIO22); also elsewhere on the board
GPIO23: U2.35 (GPIO23)
GPIO26: U2.40 (GPIO26_ADC0)
GPIO27: U2.41 (GPIO27_ADC1)
GPIO28: U2.42 (GPIO28_ADC2)
unnamed: R9.1, SW1.1
unnamed: R10.1, SW2.1
unnamed: C17.1, R1.2, U1.1 (EN)
unnamed: R4.2, U1.5 (READY)
unnamed: L1.2, U2.48 (VREG_LX)

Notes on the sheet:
no clock for now (not strictly necessary as i2c is clocked)

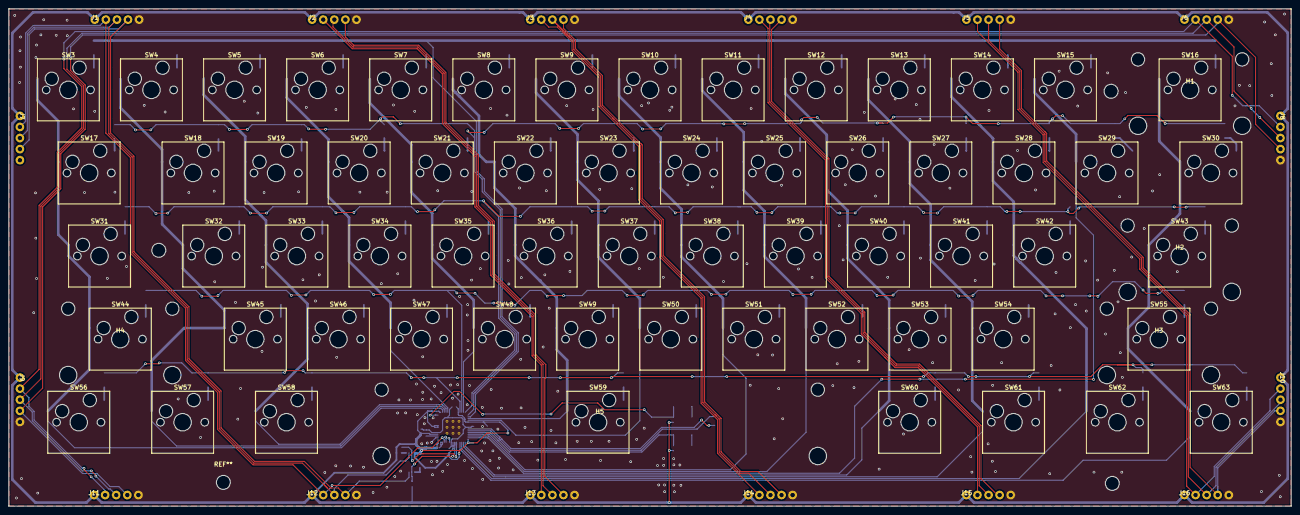
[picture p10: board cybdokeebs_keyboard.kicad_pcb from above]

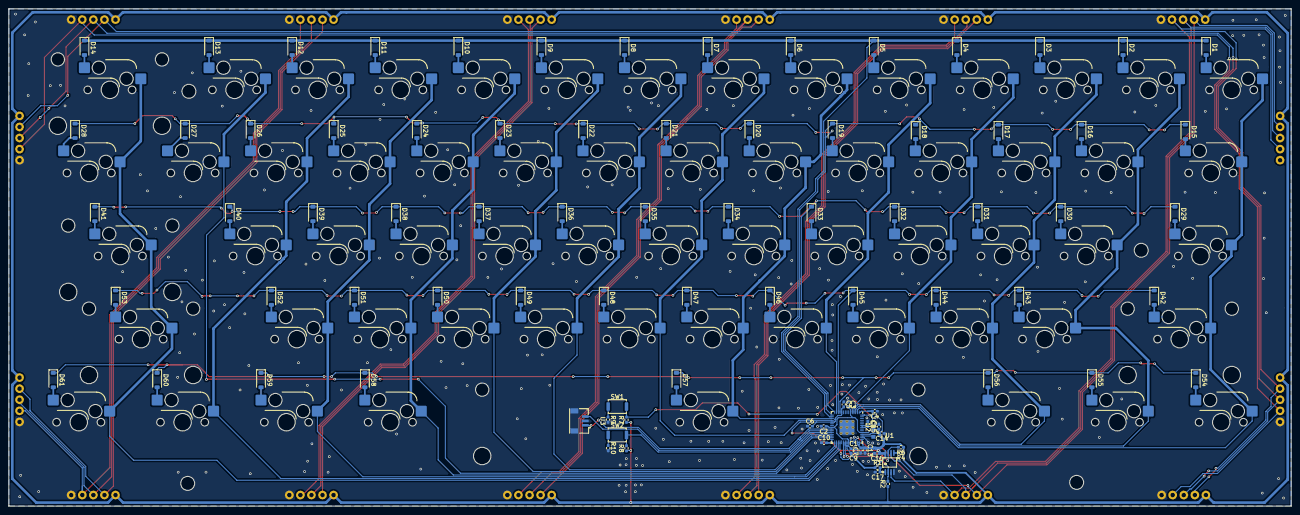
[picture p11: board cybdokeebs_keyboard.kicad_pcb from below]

Board: 2 copper layers, 294.0 x 114.0 mm, 172 parts (90 on the bottom side), 112 nets.

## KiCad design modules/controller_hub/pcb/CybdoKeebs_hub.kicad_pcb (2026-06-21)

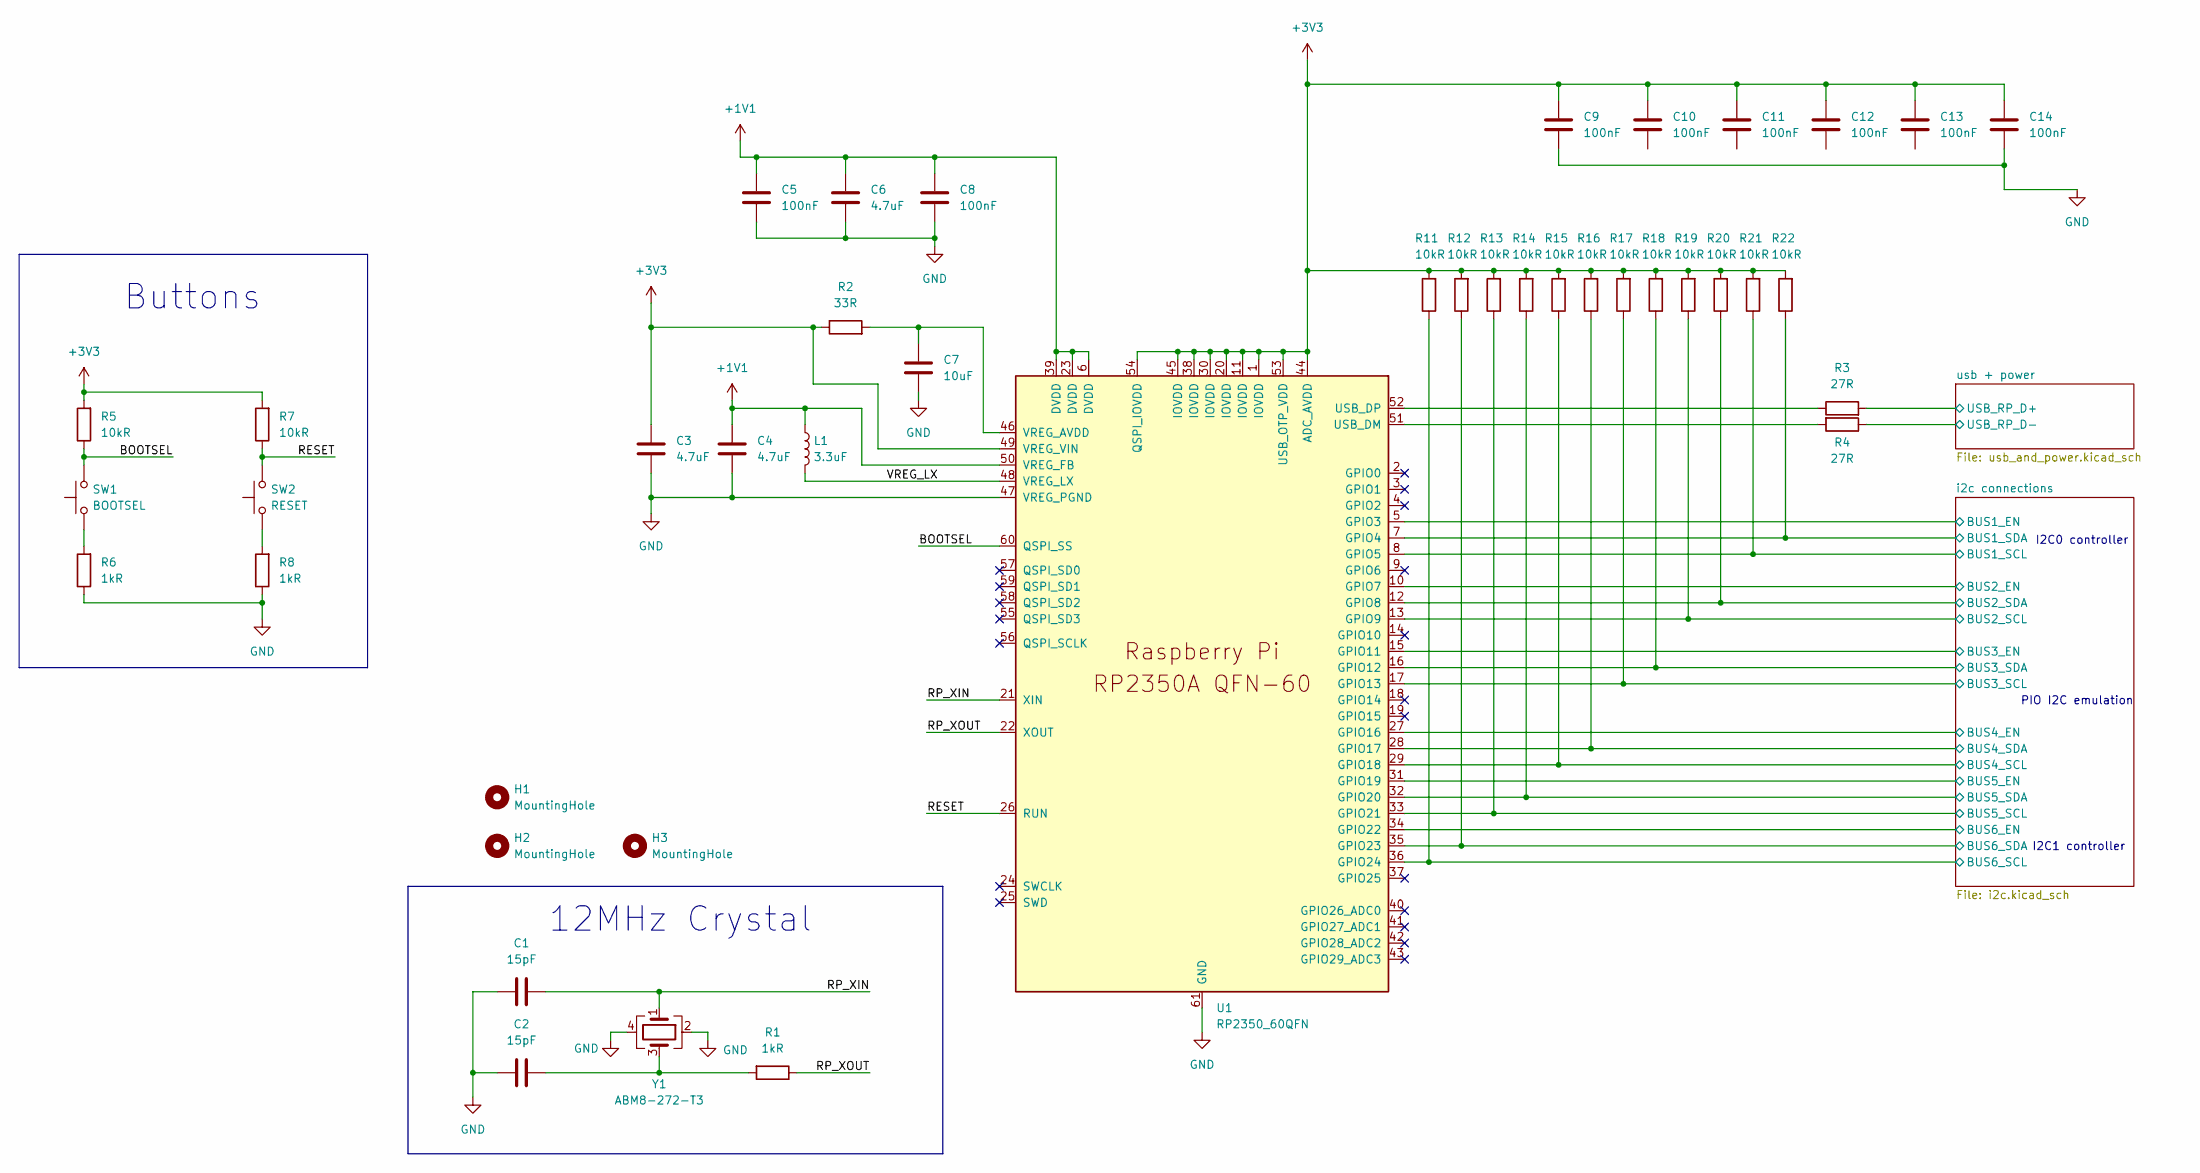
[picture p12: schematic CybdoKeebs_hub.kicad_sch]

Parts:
C1, C2: 15pF; C_0402_1005Metric_Pad0.74x0.62mm_HandSolder
C3, C4, C6: 4.7uF; C_0402_1005Metric_Pad0.74x0.62mm_HandSolder
C5, C8, C9, C10, C11, C12, C13, C14: 100nF; C_0402_1005Metric_Pad0.74x0.62mm_HandSolder
C7: 10uF; C_0402_1005Metric_Pad0.74x0.62mm_HandSolder
H1, H2, H3: MountingHole; MountingHole_3.2mm_M3
L1: 3.3uF; INDC1608X95N
R1, R6, R8: 1kR; R_0402_1005Metric_Pad0.72x0.64mm_HandSolder
R2: 33R; R_0402_1005Metric_Pad0.72x0.64mm_HandSolder
R3, R4: 27R; R_0402_1005Metric_Pad0.72x0.64mm_HandSolder
R5, R7, R11, R12, R13, R14, R15, R16, R17, R18, R19, R20, R21, R22: 10kR; R_0402_1005Metric_Pad0.72x0.64mm_HandSolder
SW1: BOOTSEL; SW_Push_SPST_NO_Alps_SKRK
SW2: RESET; SW_Push_SPST_NO_Alps_SKRK
U1: RP2350_60QFN; RP2350-QFN-60-1EP_7x7_P0.4mm_EP3.4x3.4mm_ThermalVias
Y1: ABM8-272-T3; Crystal_SMD_Abracon_ABM8G-4Pin_3.2x2.5mm

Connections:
+1V1: C4.1, C5.1, C6.1, C8.1, L1.1, U1.6 (DVDD), U1.23 (DVDD), U1.39 (DVDD), U1.50 (VREG_FB)
+3V3: C3.1, C9.1, C10.1, C11.1, C12.1, C13.1, C14.1, R2.1, R5.2, R7.2, R11.2, R12.2, R13.2, R14.2, R15.2, R16.2, R17.2, R18.2, R19.2, R20.2, R21.2, R22.2, U1.1 (IOVDD), U1.11 (IOVDD), U1.20 (IOVDD), U1.30 (IOVDD), U1.38 (IOVDD), U1.44 (ADC_AVDD), U1.45 (IOVDD), U1.49 (VREG_VIN), U1.53 (USB_OTP_VDD), U1.54 (QSPI_IOVDD); also elsewhere on the board
/BOOTSEL: R5.1, SW1.2, U1.60 (QSPI_SS)
/RESET: R7.1, SW2.2, U1.26 (RUN)
/RP_XIN: C1.2, U1.21 (XIN), Y1.1
/RP_XOUT: R1.1, U1.22 (XOUT)
/VREG_LX: L1.2, U1.48 (VREG_LX)
/i2c connections/BUS1_EN: U1.5 (GPIO3); also elsewhere on the board
/i2c connections/BUS1_SCL: R21.1, U1.8 (GPIO5); also elsewhere on the board
/i2c connections/BUS1_SDA: R22.1, U1.7 (GPIO4); also elsewhere on the board
/i2c connections/BUS2_EN: U1.10 (GPIO7); also elsewhere on the board
/i2c connections/BUS2_SCL: R19.1, U1.13 (GPIO9); also elsewhere on the board
/i2c connections/BUS2_SDA: R20.1, U1.12 (GPIO8); also elsewhere on the board
/i2c connections/BUS3_EN: U1.15 (GPIO11); also elsewhere on the board
/i2c connections/BUS3_SCL: R17.1, U1.17 (GPIO13); also elsewhere on the board
/i2c connections/BUS3_SDA: R18.1, U1.16 (GPIO12); also elsewhere on the board
/i2c connections/BUS4_EN: U1.27 (GPIO16); also elsewhere on the board
/i2c connections/BUS4_SCL: R15.1, U1.29 (GPIO18); also elsewhere on the board
/i2c connections/BUS4_SDA: R16.1, U1.28 (GPIO17); also elsewhere on the board
/i2c connections/BUS5_EN: U1.31 (GPIO19); also elsewhere on the board
/i2c connections/BUS5_SCL: R13.1, U1.33 (GPIO21); also elsewhere on the board
/i2c connections/BUS5_SDA: R14.1, U1.32 (GPIO20); also elsewhere on the board
/i2c connections/BUS6_EN: U1.34 (GPIO22); also elsewhere on the board
/i2c connections/BUS6_SCL: R11.1, U1.36 (GPIO24); also elsewhere on the board
/i2c connections/BUS6_SDA: R12.1, U1.35 (GPIO23); also elsewhere on the board
/usb + power/USB_RP_D+: R3.2; also elsewhere on the board
/usb + power/USB_RP_D-: R4.1; also elsewhere on the board
GND: C1.1, C2.1, C3.2, C4.2, C5.2, C6.2, C7.2, C8.2, C9.2, C14.2, R6.1, R8.1, U1.47 (VREG_PGND), U1.61 (GND), Y1.2, Y1.4; also elsewhere on the board
unnamed: C2.2, R1.2, Y1.3
unnamed: R6.2, SW1.1
unnamed: R8.2, SW2.1
unnamed: R4.2, U1.51 (USB_DM)
unnamed: R3.1, U1.52 (USB_DP)
unnamed: C7.1, R2.2, U1.46 (VREG_AVDD)

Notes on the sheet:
PIO I2C emulation
I2C0 controller
I2C1 controller
Buttons
12MHz Crystal

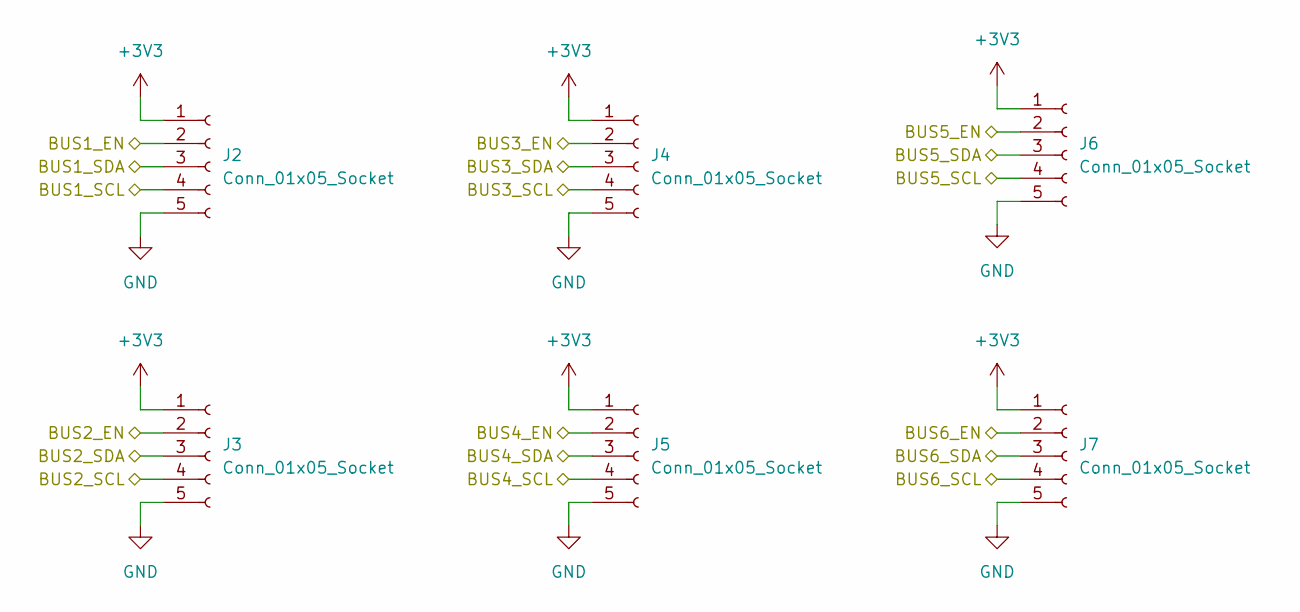
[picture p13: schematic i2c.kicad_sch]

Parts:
J2, J3, J4, J5, J6, J7: Conn_01x05_Socket; pogo 5pin 2.54

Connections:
+3V3: J2.1, J3.1, J4.1, J5.1, J6.1, J7.1; also elsewhere on the board
/i2c connections/BUS1_EN: J2.2; also elsewhere on the board
/i2c connections/BUS1_SCL: J2.4; also elsewhere on the board
/i2c connections/BUS1_SDA: J2.3; also elsewhere on the board
/i2c connections/BUS2_EN: J3.2; also elsewhere on the board
/i2c connections/BUS2_SCL: J3.4; also elsewhere on the board
/i2c connections/BUS2_SDA: J3.3; also elsewhere on the board
/i2c connections/BUS3_EN: J4.2; also elsewhere on the board
/i2c connections/BUS3_SCL: J4.4; also elsewhere on the board
/i2c connections/BUS3_SDA: J4.3; also elsewhere on the board
/i2c connections/BUS4_EN: J5.2; also elsewhere on the board
/i2c connections/BUS4_SCL: J5.4; also elsewhere on the board
/i2c connections/BUS4_SDA: J5.3; also elsewhere on the board
/i2c connections/BUS5_EN: J6.2; also elsewhere on the board
/i2c connections/BUS5_SCL: J6.4; also elsewhere on the board
/i2c connections/BUS5_SDA: J6.3; also elsewhere on the board
/i2c connections/BUS6_EN: J7.2; also elsewhere on the board
/i2c connections/BUS6_SCL: J7.4; also elsewhere on the board
/i2c connections/BUS6_SDA: J7.3; also elsewhere on the board
GND: J2.5, J3.5, J4.5, J5.5, J6.5, J7.5; also elsewhere on the board

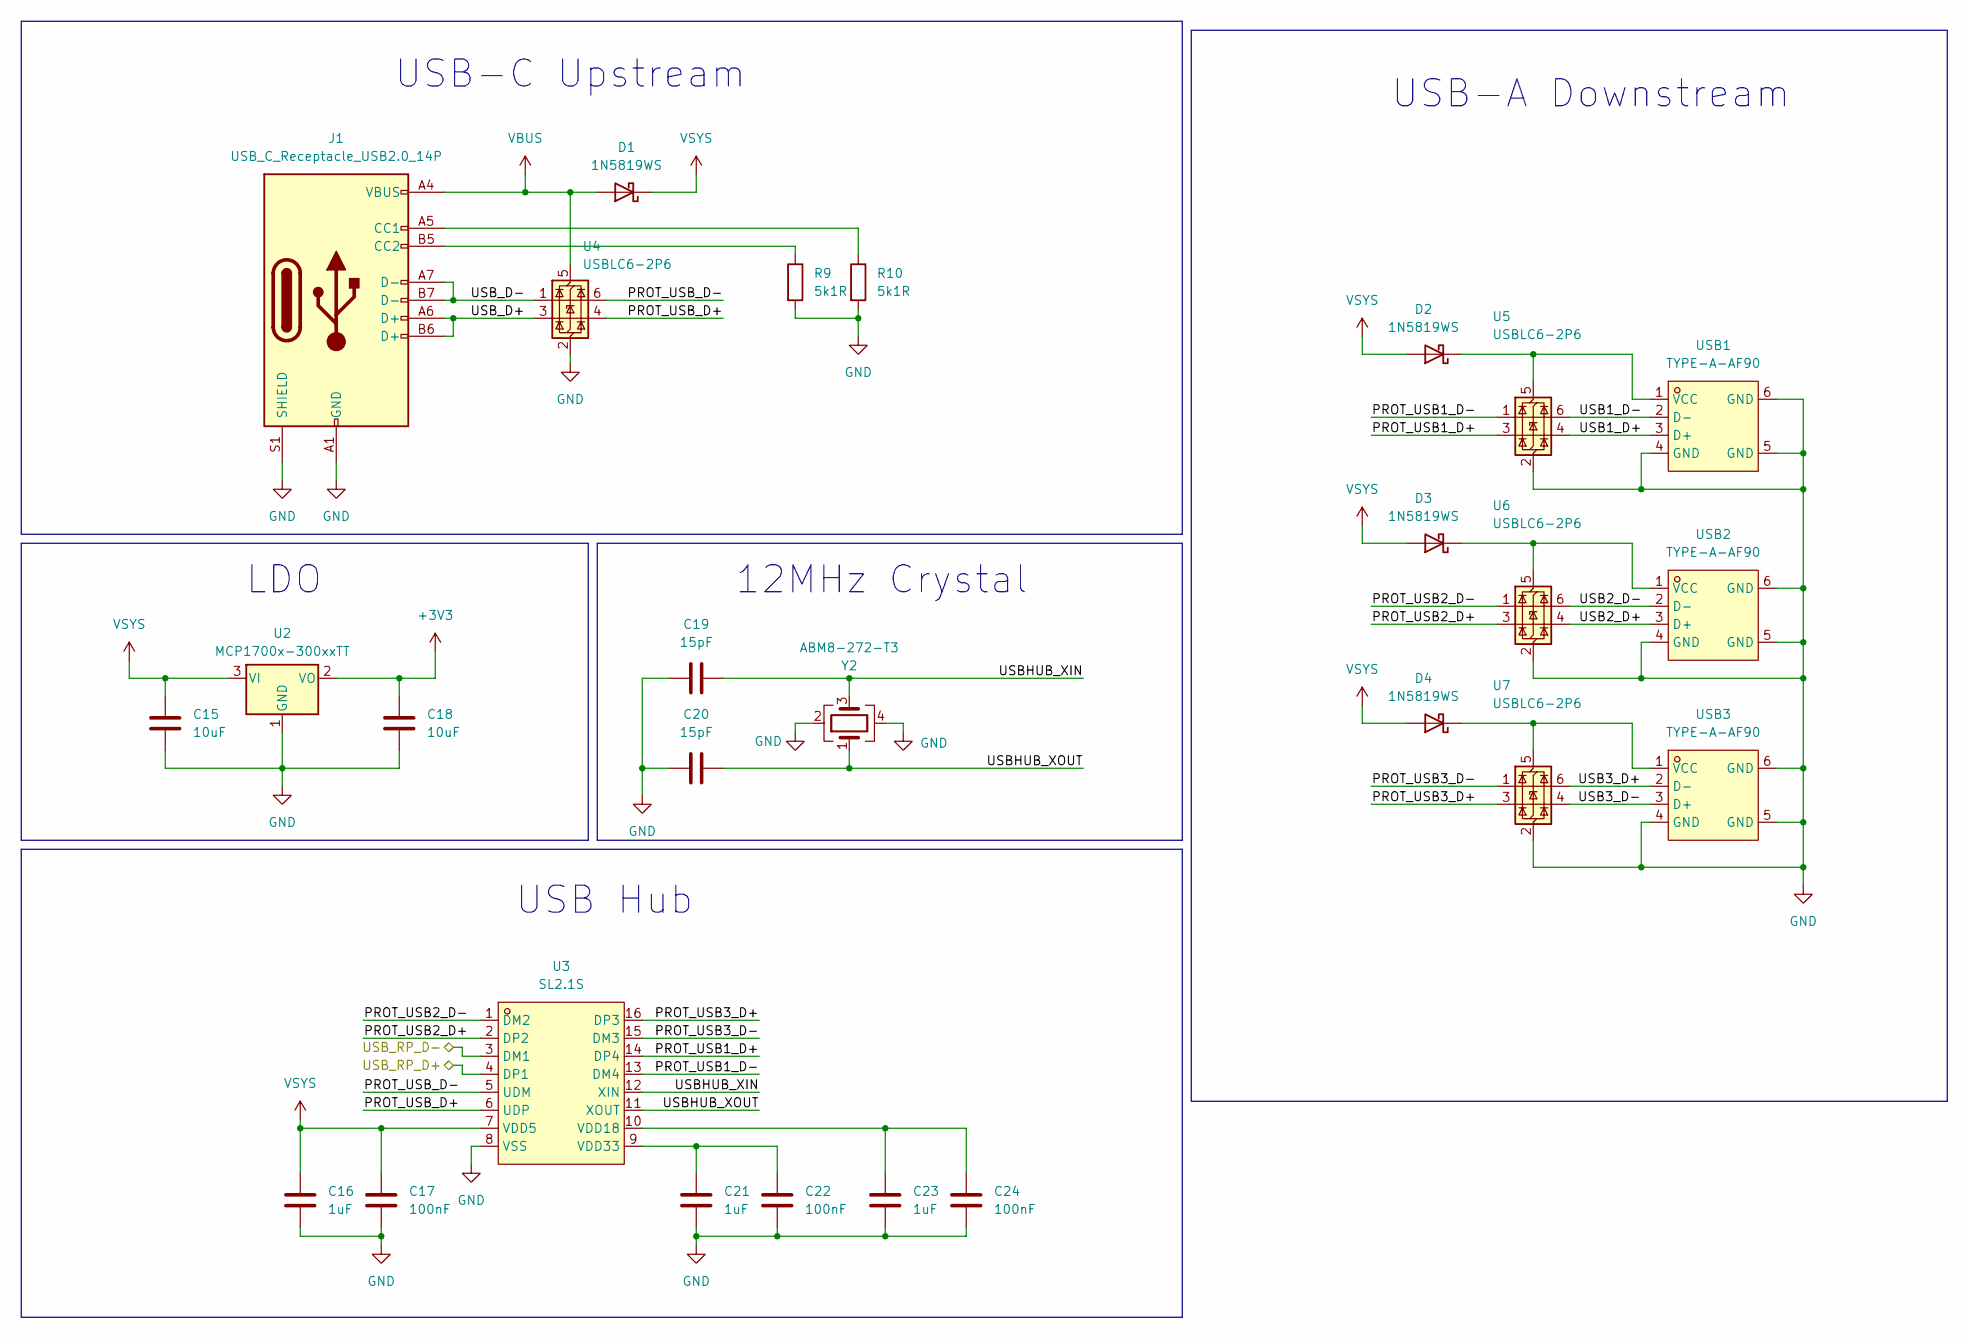
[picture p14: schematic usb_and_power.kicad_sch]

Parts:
C15, C18: 10uF; C_0402_1005Metric_Pad0.74x0.62mm_HandSolder
C16, C21, C23: 1uF; C_0402_1005Metric_Pad0.74x0.62mm_HandSolder
C17, C22, C24: 100nF; C_0402_1005Metric_Pad0.74x0.62mm_HandSolder
C19, C20: 15pF; C_0402_1005Metric_Pad0.74x0.62mm_HandSolder
D1, D2, D3, D4: 1N5819WS; D_SOD-323
J1: USB_C_Receptacle_USB2.0_14P; USB_C_Receptacle_HRO_TYPE-C-31-M-12
R9, R10: 5k1R; R_0402_1005Metric_Pad0.72x0.64mm_HandSolder
U2: MCP1700x-300xxTT; SOT-23
U3: SL2.1S; SSOP-16_L4.6-W2.6-P0.53-LS4.0-BL; MPN SL2.1s; LCSC Part C2684433
U4, U5, U6, U7: USBLC6-2P6; SOT-666
USB1, USB2, USB3: TYPE-A-AF90; USB-A-TH_U-A-24DD-Y-13; MPN Type-A-AF90; LCSC Part C53207796
Y2: ABM8-272-T3; Crystal_SMD_Abracon_ABM8G-4Pin_3.2x2.5mm

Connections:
+3V3: C18.1, U2.2 (VO); also elsewhere on the board
/usb + power/PROT_USB1_D+: U3.14 (DP4), U5.3 (I/O2)
/usb + power/PROT_USB1_D-: U3.13 (DM4), U5.1 (I/O1)
/usb + power/PROT_USB2_D+: U3.2 (DP2), U6.3 (I/O2)
/usb + power/PROT_USB2_D-: U3.1 (DM2), U6.1 (I/O1)
/usb + power/PROT_USB3_D+: U3.16 (DP3), U7.3 (I/O2)
/usb + power/PROT_USB3_D-: U3.15 (DM3), U7.1 (I/O1)
/usb + power/PROT_USB_D+: U3.6 (UDP), U4.4 (I/O2)
/usb + power/PROT_USB_D-: U3.5 (UDM), U4.6 (I/O1)
/usb + power/USB1_D+: U5.4 (I/O2), USB1.3 (D+)
/usb + power/USB1_D-: U5.6 (I/O1), USB1.2 (D-)
/usb + power/USB2_D+: U6.4 (I/O2), USB2.3 (D+)
/usb + power/USB2_D-: U6.6 (I/O1), USB2.2 (D-)
/usb + power/USB3_D+: U7.6 (I/O1), USB3.2 (D-)
/usb + power/USB3_D-: U7.4 (I/O2), USB3.3 (D+)
/usb + power/USBHUB_XIN: C19.2, U3.12 (XIN), Y2.3
/usb + power/USBHUB_XOUT: C20.2, U3.11 (XOUT), Y2.1
/usb + power/USB_D+: J1.A6 (D+), J1.B6 (D+), U4.3 (I/O2)
/usb + power/USB_D-: J1.A7 (D-), J1.B7 (D-), U4.1 (I/O1)
/usb + power/USB_RP_D+: U3.4 (DP1); also elsewhere on the board
/usb + power/USB_RP_D-: U3.3 (DM1); also elsewhere on the board
GND: C15.2, C16.2, C17.2, C18.2, C19.1, C20.1, C21.2, C22.2, C23.2, C24.2, J1.A1 (GND), J1.A12 (GND), J1.B1 (GND), J1.B12 (GND), J1.S1 (SHIELD), R9.2, R10.2, U2.1 (GND), U3.8 (VSS), U4.2 (GND), U5.2 (GND), U6.2 (GND), U7.2 (GND), USB1.4 (GND), USB1.5 (GND), USB1.6 (GND), USB2.4 (GND), USB2.5 (GND), USB2.6 (GND), USB3.4 (GND), USB3.5 (GND), USB3.6 (GND), Y2.2, Y2.4; also elsewhere on the board
unnamed: D2.1 (K), U5.5 (VBUS), USB1.1 (VCC)
unnamed: D3.1 (K), U6.5 (VBUS), USB2.1 (VCC)
unnamed: D4.1 (K), U7.5 (VBUS), USB3.1 (VCC)
unnamed: J1.A5 (CC1), R10.1
unnamed: J1.B5 (CC2), R9.1
unnamed: C23.1, C24.1, U3.10 (VDD18)
unnamed: C21.1, C22.1, U3.9 (VDD33)
VBUS: D1.2 (A), J1.A4 (VBUS), J1.A9 (VBUS), J1.B4 (VBUS), J1.B9 (VBUS), U4.5 (VBUS)
VSYS: C15.1, C16.1, C17.1, D1.1 (K), D2.2 (A), D3.2 (A), D4.2 (A), U2.3 (VI), U3.7 (VDD5)

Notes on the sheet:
LDO
USB-C Upstream
USB Hub
12MHz Crystal
USB-A Downstream

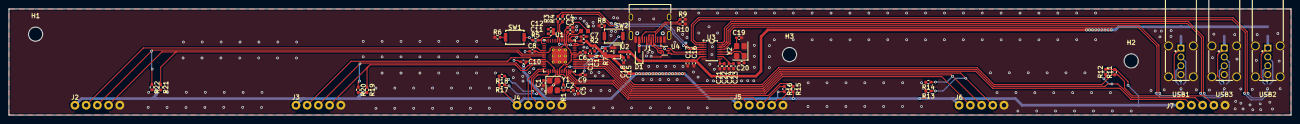
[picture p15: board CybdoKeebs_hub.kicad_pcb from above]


Board: 2 copper layers, 290.0 x 24.0 mm, 75 parts (6 on the bottom side), 61 nets.

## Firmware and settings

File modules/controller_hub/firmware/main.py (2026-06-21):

import time

import board
import busio
import digitalio
import usb_hid
from adafruit_hid.keyboard import Keyboard
from adafruit_hid.keycode import Keycode


I2C_ADDRESS = 0x42
REPORT_LENGTH = 8

MODIFIER_KEYCODES = [
	Keycode.LEFT_CONTROL,
	Keycode.LEFT_SHIFT,
	Keycode.LEFT_ALT,
	Keycode.LEFT_GUI,
	Keycode.RIGHT_CONTROL,
	Keycode.RIGHT_SHIFT,
	Keycode.RIGHT_ALT,
	Keycode.RIGHT_GUI,
]

bus1interrupt = digitalio.DigitalInOut(board.GP3)
bus1interrupt.direction = digitalio.Direction.INPUT
bus1interrupt.pull = digitalio.Pull.DOWN
bus1i2c = busio.I2C(board.GP5, board.GP4, frequency=100000)

bus2interrupt = digitalio.DigitalInOut(board.GP7)
bus2interrupt.direction = digitalio.Direction.INPUT
bus2interrupt.pull = digitalio.Pull.DOWN
bus2i2c = busio.I2C(board.GP9, board.GP8, frequency=100000)

bus3interrupt = digitalio.DigitalInOut(board.GP11)
bus3interrupt.direction = digitalio.Direction.INPUT
bus3interrupt.pull = digitalio.Pull.DOWN
bus3i2c = busio.I2C(board.GP13, board.GP12, frequency=100000)

bus4interrupt = digitalio.DigitalInOut(board.GP16)
bus4interrupt.direction = digitalio.Direction.INPUT
bus4interrupt.pull = digitalio.Pull.DOWN
bus4i2c = busio.I2C(board.GP18, board.GP17, frequency=100000)

bus5interrupt = digitalio.DigitalInOut(board.GP19)
bus5interrupt.direction = digitalio.Direction.INPUT
bus5interrupt.pull = digitalio.Pull.DOWN
bus5i2c = busio.I2C(board.GP21, board.GP20, frequency=100000)

bus6interrupt = digitalio.DigitalInOut(board.GP22)
bus6interrupt.direction = digitalio.Direction.INPUT
bus6interrupt.pull = digitalio.Pull.DOWN
bus6i2c = busio.I2C(board.GP24, board.GP23, frequency=100000)


keyboard = Keyboard(usb_hid.devices)

BUSES = [
	{"interrupt": bus1interrupt, "i2c": bus1i2c, "report": bytearray(REPORT_LENGTH), "last_report": bytes(REPORT_LENGTH)},
	{"interrupt": bus2interrupt, "i2c": bus2i2c, "report": bytearray(REPORT_LENGTH), "last_report": bytes(REPORT_LENGTH)},
	{"interrupt": bus3interrupt, "i2c": bus3i2c, "report": bytearray(REPORT_LENGTH), "last_report": bytes(REPORT_LENGTH)},
	{"interrupt": bus4interrupt, "i2c": bus4i2c, "report": bytearray(REPORT_LENGTH), "last_report": bytes(REPORT_LENGTH)},
	{"interrupt": bus5interrupt, "i2c": bus5i2c, "report": bytearray(REPORT_LENGTH), "last_report": bytes(REPORT_LENGTH)},
	{"interrupt": bus6interrupt, "i2c": bus6i2c, "report": bytearray(REPORT_LENGTH), "last_report": bytes(REPORT_LENGTH)},
]


def _read_report(i2c_bus, report_buffer):
    while not i2c_bus.try_lock():
        pass
    
    i2c_bus.readfrom_into(I2C_ADDRESS, report_buffer)
    i2c_bus.unlock()
    return bytes(report_buffer)




def _aggregate_state():
	modifiers = 0
	keys = []
	seen_keys = set()

	for bus in BUSES:
		report = bus["report"]
		modifiers |= report[0]

		key_count = report[1]
		if key_count > 6:
			key_count = 6

		for keycode in report[2 : 2 + key_count]:
			if keycode and keycode not in seen_keys:
				seen_keys.add(keycode)
				keys.append(keycode)
				if len(keys) == 6:
					break

	return modifiers, keys


def _sync_keyboard_state(desired_modifiers, desired_keys, current_modifiers, current_keys):
	released_modifiers = []
	pressed_modifiers = []

	for bit_index, keycode in enumerate(MODIFIER_KEYCODES):
		bit = 1 << bit_index
		if current_modifiers & bit and not desired_modifiers & bit:
			released_modifiers.append(keycode)
		elif desired_modifiers & bit and not current_modifiers & bit:
			pressed_modifiers.append(keycode)

	released_keys = [keycode for keycode in current_keys if keycode not in desired_keys]
	pressed_keys = [keycode for keycode in desired_keys if keycode not in current_keys]

	if released_modifiers or released_keys:
		keyboard.release(*(released_modifiers + released_keys))
	if pressed_modifiers or pressed_keys:
		keyboard.press(*(pressed_modifiers + pressed_keys))

	return desired_modifiers, desired_keys[:]


def main():
	current_modifiers = 0
	current_keys = []

	while True:
		updated = False

		for bus in BUSES:
			if not bus["interrupt"].value:
				continue

			report = _read_report(bus["i2c"], bus["report"])
			if report is None:
				continue

			if report != bus["last_report"]:
				bus["last_report"] = report
				updated = True

		if updated:
			for bus in BUSES:
				bus["report"][:] = bus["last_report"]

			desired_modifiers, desired_keys = _aggregate_state()
			if desired_modifiers != current_modifiers or desired_keys != current_keys:
				current_modifiers, current_keys = _sync_keyboard_state(
					desired_modifiers,
					desired_keys,
					current_modifiers,
					current_keys,
				)

		time.sleep(0.001)


main()

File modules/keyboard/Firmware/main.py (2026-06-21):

import time

import board
import digitalio
from adafruit_hid.keycode import Keycode

try:
    from i2ctarget import I2CTarget
except ImportError:
    I2CTarget = None


I2C_ADDRESS = 0x42
REPORT_LENGTH = 8
DEBOUNCE_SECONDS = 0.02
INTERRUPT_PULSE_SECONDS = 0.03

matrix = [
    ["esc", "1", "2", "3", "4", "5", "6", "7", "8", "9", "0", "-", "=", "backspace"],
    ["tab", "q", "w", "e", "r", "t", "y", "u", "i", "o", "p", "[", "]", "\\"],
    ["capslock", "a", "s", "d", "f", "g", "h", "j", "k", "l", ";", "'", None, "enter"],
    ["Lshift", "z", "x", "c", "v", "b", "n", "m", ",", ".", "/", None, None, "Rshift"],
    ["Lctrl", "Lwin", "Lalt", None, None, "Space", None, None, None, None, None, "Ralt", "Rwin", "Rctrl"],
]

interrupt = digitalio.DigitalInOut(board.GP29)
interrupt.direction = digitalio.Direction.OUTPUT
interrupt.value = False

column_pins = [
    digitalio.DigitalInOut(board.GP0),
    digitalio.DigitalInOut(board.GP1),
    digitalio.DigitalInOut(board.GP2),
    digitalio.DigitalInOut(board.GP3),
    digitalio.DigitalInOut(board.GP10),
    digitalio.DigitalInOut(board.GP14),
    digitalio.DigitalInOut(board.GP15),
    digitalio.DigitalInOut(board.GP16),
    digitalio.DigitalInOut(board.GP17),
    digitalio.DigitalInOut(board.GP19),
    digitalio.DigitalInOut(board.GP20),
    digitalio.DigitalInOut(board.GP21),
    digitalio.DigitalInOut(board.GP18),
    digitalio.DigitalInOut(board.GP22),
]

row_pins = [
    digitalio.DigitalInOut(board.GP13),
    digitalio.DigitalInOut(board.GP12),
    digitalio.DigitalInOut(board.GP11),
    digitalio.DigitalInOut(board.GP9),
    digitalio.DigitalInOut(board.GP8),
]

for column_pin in column_pins:
    column_pin.direction = digitalio.Direction.OUTPUT
    column_pin.value = True

for row_pin in row_pins:
    row_pin.direction = digitalio.Direction.INPUT
    row_pin.pull = digitalio.Pull.UP


KEYCODES = {
    "esc": Keycode.ESCAPE,
    "1": Keycode.ONE,
    "2": Keycode.TWO,
    "3": Keycode.THREE,
    "4": Keycode.FOUR,
    "5": Keycode.FIVE,
    "6": Keycode.SIX,
    "7": Keycode.SEVEN,
    "8": Keycode.EIGHT,
    "9": Keycode.NINE,
    "0": Keycode.ZERO,
    "-": Keycode.MINUS,
    "=": Keycode.EQUALS,
    "backspace": Keycode.BACKSPACE,
    "tab": Keycode.TAB,
    "q": Keycode.Q,
    "w": Keycode.W,
    "e": Keycode.E,
    "r": Keycode.R,
    "t": Keycode.T,
    "y": Keycode.Y,
    "u": Keycode.U,
    "i": Keycode.I,
    "o": Keycode.O,
    "p": Keycode.P,
    "[": Keycode.LEFT_BRACKET,
    "]": Keycode.RIGHT_BRACKET,
    "\\": Keycode.BACKSLASH,
    "capslock": Keycode.CAPS_LOCK,
    "a": Keycode.A,
    "s": Keycode.S,
    "d": Keycode.D,
    "f": Keycode.F,
    "g": Keycode.G,
    "h": Keycode.H,
    "j": Keycode.J,
    "k": Keycode.K,
    "l": Keycode.L,
    ";": Keycode.SEMICOLON,
    "'": Keycode.QUOTE,
    "enter": Keycode.ENTER,
    "z": Keycode.Z,
    "x": Keycode.X,
    "c": Keycode.C,
    "v": Keycode.V,
    "b": Keycode.B,
    "n": Keycode.N,
    "m": Keycode.M,
    ",": Keycode.COMMA,
    ".": Keycode.PERIOD,
    "/": Keycode.FORWARD_SLASH,
    "Space": Keycode.SPACEBAR,
}

MODIFIER_BITS = {
    "Lctrl": 0x01,
    "Lshift": 0x02,
    "Lalt": 0x04,
    "Lwin": 0x08,
    "Rctrl": 0x10,
    "Rshift": 0x20,
    "Ralt": 0x40,
    "Rwin": 0x80,
}


def _set_interrupt(active):
    interrupt.value = active


def _scan_matrix():
    modifiers = 0
    keys = []
    seen_keys = set()

    for column_index, column_pin in enumerate(column_pins):
        column_pin.value = False
        for row_index, row_pin in enumerate(row_pins):
            if not row_pin.value:
                key_name = matrix[row_index][column_index]
                if key_name is None:
                    continue

                modifier_bit = MODIFIER_BITS.get(key_name)
                if modifier_bit is not None:
                    modifiers |= modifier_bit
                    continue

                keycode = KEYCODES.get(key_name)
                if keycode is not None and keycode not in seen_keys:
                    seen_keys.add(keycode)
                    keys.append(keycode)
        column_pin.value = True

    report = bytearray(REPORT_LENGTH)
    report[0] = modifiers
    report[1] = 0
    for index, keycode in enumerate(keys[:6], start=2):
        report[index] = keycode
    return bytes(report)


def _serve_i2c(target, report):
    request = target.request()
    if request is None:
        return

    with request as transaction:
        if transaction.is_read:
            transaction.write(report)
        elif transaction.is_write:
            transaction.readinto(bytearray(REPORT_LENGTH))


def main():
    if I2CTarget is None:
        raise RuntimeError("i2ctarget is required for the keyboard peripheral firmware")

    stable_report = _scan_matrix()
    candidate_report = stable_report
    candidate_since = time.monotonic()
    interrupt_clear_at = 0.0

    with I2CTarget(board.GP25, board.GP24, (I2C_ADDRESS,)) as target:
        while True:
            now = time.monotonic()
            current_report = _scan_matrix()

            if current_report != candidate_report:
                candidate_report = current_report
                candidate_since = now
            elif current_report != stable_report and now - candidate_since >= DEBOUNCE_SECONDS:
                stable_report = current_report
                _set_interrupt(True)
                interrupt_clear_at = now + INTERRUPT_PULSE_SECONDS

            if interrupt_clear_at and now >= interrupt_clear_at:
                _set_interrupt(False)
                interrupt_clear_at = 0.0

            _serve_i2c(target, stable_report)

            time.sleep(0.001)


main()

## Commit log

2026-04-23 started on control hub
    [CybdoKeebs_hub.kicad_pcb, CybdoKeebs_hub.kicad_sch]
2026-04-25 finish minimum system, add i2c connectors
    [CybdoKeebs_hub.kicad_pcb, CybdoKeebs_hub.kicad_sch, i2c.kicad_sch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]
2026-04-28 add template for each module
    [CybdoKeebs_hub.kicad_sch, cybdokeebs_template.kicad_pcb, cybdokeebs_template.kicad_sch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]
2026-06-12 hub done, started macropad
    [ABM8-272-T3.step, CybdoKeebs_hub.kicad_pcb, CybdoKeebs_hub.kicad_sch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]
2026-06-20 macropad finished
    [cybdokeebs_macropad.kicad_pcb, cybdokeebs_macropad.kicad_sch, minimum_system.kicad_sch]
2026-06-20 started main keyboard
    [cybdokeebs_keyboard.kicad_pcb, cybdokeebs_keyboard.kicad_sch, cybdokeebs_macropad.kicad_pcb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]
2026-06-21 kb mostly done
    [cybdokeebs_keyboard.kicad_pcb, cybdokeebs_keyboard.kicad_sch, minimum_system.kicad_sch]
2026-06-21 finished all pcbs
    [CybdoKeebs_hub.kicad_pcb, CybdoKeebs_hub.kicad_sch, case.step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]
2026-06-21 zine!! and cases
    [case.step, cybdokeebs_macropad.kicad_pcb, pcb.step]
2026-06-21 ship ship ship!!!
    [CybdoKeebs_hub.kicad_sch, bom-lcsc-minimum-system.xls, bom.csv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]
2026-06-23 oops forgor assembly step
    [cybdokeebs.step]
2026-06-23 git lfs
    [ABM8-272-T3.step, case.step, pcb.step]
2026-06-23 macropad holes line up now
    not updated in assembly.step but they line up now
    [cybdokeebs_macropad.kicad_pcb]
2026-06-24 updated BOM to include hub-specific components
    [bom-lcsc-hub.xls, bom.csv, bom_CybdoKeebs_hub.csv]
2026-06-25 updates stuffs
    [assembled.step, bom.csv, case.step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]
2026-06-27 new case and cads
    [assembled.step, case.step, cybdokeebs.step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]
2026-06-27 polish up cad
    [assembled.step, cybdokeebs.step, cybdokeebs_keyboard.kicad_pcb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]
